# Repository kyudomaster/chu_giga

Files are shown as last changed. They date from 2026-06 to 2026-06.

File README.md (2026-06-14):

# Chu Giga Project Overview

## Project goal

This project aims to create an open-source Chunithm controller using a Raspberry Pi Pico.
The hardware and overall design is heavily inspired by [WhoWeChina's chu_pico controller](https://github.com/whowechina/chu_pico).

This project also includes software that can be used with SegaTools-Compatible game dumps.

We try to fully document the design and include instructions on how to build this controller yourself.

## Current status

We have barely even gotten started lmao:

### PCB

25%
There are first prototypes of the PCBs already, the ToF boards seem to be great, but the slider currently has the wrong pinout for LEDs so a new version needs to be made and tested.
The mainboard has not been properly tested yet and may need more power input to handle all the LEDs.

### Firmware

5%
Basic sensor drivers exist, but require some more work.
There is no firmware for LEDs or actual input handling yet.

### Software

0%
We only figured out that we need our own `chuniio.dll` today.

### CAD

10%
There is a first version of the LGP panel for the slider, but nothing has been made or tested yet.
The actual case and other components also do not exist yet.

## Features

The controller uses:

- A 32-zone capacitive PCB slider. (MPR121)
- 12 ToF Air sensors. (VL53L0X)
- 3 utility buttons. (Test, Service and Coin)
- RGB Lighting for the slider. (Slider only)

## Project Scope

This repository aims to document not only the final implementation, but also the reasoning behind the design decisions. (Or lack of reasoning when that is applicable :3)

The goal is that a future contributor should be able to understand:

- How the controller works.
- Why the specific hardware was chosen.
- How the firmware is structured.
- How communication with the game works.
- How to build your own controller.

## Supported Software

The controller is intended to support:

- Chunithm cabinet dumps through segatools.
- Umiguri.
- Maybe other games... (simple keyboard output)

Additional software may be supported in the future. (The ToF sensors technically allow for 2 Axis movement.)

## Major Components

The project consists of 4 major components:

### 1. Hardware

Documentation covering:

- PCB Designs.
- Schematics.
- Component choices.
- Assembly instructions.

### 2. Mechanical Design

Documentation covering:

- CAD Files.
- Printed/CNCd parts.
- Additional parts.
- Assembly instructions.

### 3. Firmware

Firmware running on a Raspberry Pi Pico.

Responsibilities include:

- Reading sensors.
- Processing inputs.
- Managing calibration.
- Communicating with the PC.

### 4. PC Interface Software

A custom `chuniio.dll` implementation to be used with SegaTools.

Responsibilities include:

- Receiving controller input.
- Translating controller state into SegaTools-compatible input.
- Providing an interface between the controller and the game.

## Documentation

The documentation is organized into the separate major components and build, assembly and installation guides.
You can find said documentation in the [`docs`](docs/Introduction.md)

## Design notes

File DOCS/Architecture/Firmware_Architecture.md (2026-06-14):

# Firmware Architecture

This section details how the firmware running on the Raspberry Pi Pico is structured.

## Responsibilities

The firmware is responsible for:

- Reading the sensors on the controller, both the capacitive touch and ToF sensors.
- Processing this sensor data into 'input'.
- Maintaining a controller state.
- Communicating this state with the PC.
- Taking LED information from the PC and providing this to the LEDs on the slider PCB.

The firmware is not responsible for:

- Anything game-specific.
- SegaTools integration.
- Input mapping in the game.

## Layers

The firmware consists of different layers which only talk to the layer beneath them.

We have the physical hardware which feeds into sensor boards; 12 VL53L0X ToF sensors and 3 MPR121 Capacitive touch sensors.

We have drivers which can talk to the sensors over i2c.

The input processing talks to the drivers and converts that information into actual inputs.

The controller state checks what inputs are given at any moment and the USB communication provides the state to the PC.

The communication also takes back in LED information from the PC and provides it to the LED Drivers.

## Controller state

The firmware maintains a hardware-agnostic Controller state.
Different communication layers may expose this state as a Chunithm-specific device, a generic game controller, or a keyboard without affecting the underlying sensor processing.

Chunithm itself only requires 32 Zones and 6 Air zones. But with our hardware, it's possible to measure when we are between touch zones on the PCB too... , meaning we can have up to 93 touch zones and a free moving air zone. (With both height and X-location information.)

Regardless, the state should contain information about which of the utility buttons are pressed, and which ground and air zones are touched.

The controller state is independent from any communication protocol. Multiple communication interfaces may expose the same state simultaneously, allowing compatibility with different software without changing firmware configuration.

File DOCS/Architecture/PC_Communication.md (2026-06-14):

# PC Communication

The game is hooked into by segatools which acts as if the game is actually running in a cabinet and handles all IO etc.
Segatools has its own chuniio.dll included in chunihook.dll, which takes keyboard input and maps it to the slider.

sdfghjkl mapping to four touch zones on the slider each and space to all IR leds in the air.

A custom chuniio can be made depending on a controller which will handle communication between the game and the controller. (The raspberry pi pico in this case)

This `.dll` will check what the current state of the pico is. (buttons pressed... slider touched... airstrings played)

## Outputs

There are 3 different output types currently implemented in the controller.

One with an accompanying `chuniio.dll` for the arcade dumps.
One Game controller with axes etc.
One NKRO Keyboard.

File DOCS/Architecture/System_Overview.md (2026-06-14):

# System Overview

The Chu Giga controller intends to emulate a real original Chunithm controller, with a 32-zone slider and 'Air strings'.
Instead of using interrupting IR sensors in 6 rows in the air, we are using 12 ToF sensors to emulate this behaviour instead. The main reason for this being space savings.

A completely flat controller like this is easier to store away and requires less setup when grabbing it out of storage for a quick game.

## Original hardware [ref](https://blog.pinapelz.com/blog/umiguri/)

The original Chunithm controller has a ground slider input and air input, as well as 2 utility buttons and LED lighting.

The ground slider corresponds to 16 touch zones in the game, but actually has 32 touch zones itself because some harder songs require touches while holding a note.

The 'Air strings' are 6 Infrared LEDs on one side, and 6 receivers on the other side in the air above the slider.
Interrupting the beams is how the game detects air input.

The game also reads 2 utility buttons (Test and Service) and typically has a coin slot for credits.

Furthermore, the original controller has LED lighting all over, and most importantly on the ground slider itself, Illuminating the 16 touch zones and dividers between the zones. (31 LEDs total).

We mostly include these four separate features in the Chu Giga controller.

## System Requirements

We want this controller to be to scale with the arcade version, which guides most of the slider dimensions.

Other than that we also must have:

- 32 independent slider zones.
- Some form of Air input which corresponds to 6 different zones.
- The input to be low latency enough to play the game.
- The controller to be compatible with SegaTools to play with arcade dumps.
- The controller should also be compatible with other games... so emulating a keyboard or a controller is appropriate.

## Physical Architecture

To keep costs down and assembly reasonable and more fool-proof, since I had very little experience with electronic design before this, the controller is split up into separate components.

- There is one PCB for the ground slider.
- There are two separate PCBs for the air strings.
- There is one 'mainboard' that the other PCBs connect to, and which in turn connects to the PC.
- All PCBs are kept in place with an enclosure which can be 3D-printed or partially CNC milled.
- There are several other parts like a light guide plate, diffusion film etc. inspired by the chu_pico by [WhoWeChina](https://github.com/whowechina/chu_pico)

## Electronic Architecture

The controller uses capacitive touch sensors for the ground slider. This is an easy and cheap way to get touch input like we want it, and it allows for the PCB to be quite simple.

The air strings use time of flight sensors rather than IR beam interruption. The main reason for this being that this allows for slightly more flexible input, and that the air strings can be in plane with the ground slider, meaning the entire controller can be flat and compact.

The controller uses a Raspberry Pi Pico for processing and communication (RP2040) and the ground slider has 33 RGB LEDs, one for all 16 horizontal zones, and 17 for the dividers. (With 2 extra on both ends.)

Furthermore, there are 3 buttons to emulate the Test, Service, and Coin functions of the original controller.

## Software Architecture

For the controller to communicate with the game, we must emulate a 'real controller'.

Thankfuly we do not need to do the work for this, but we can 'simply' use SegaTools.
SegaTools can either use keyboard input or a custom `.dll` for the controller.

Since I'm in this deep already, I decided to go for a custom `chuniio.dll` which is the bridge between the game and the controller.

The controller handles the USB Communication and some sensor processing.

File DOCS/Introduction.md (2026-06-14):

# Chu Giga Documentation

Welcome to the Chu Giga documentation.

This documentation covers the hardware, firmware, software, and assembly process of the project.

## Architecture

Documentation describing how the system is designed.

- [System Overview](Architecture/System_Overview.md)
- [Firmware Architecture](Architecture/Firmware_Architecture.md)
- [PC Communication](Architecture/PC_Communication.md)
- [Controller State](Architecture/Controller_State.md)

## Hardware

Documentation describing the electronics and the 3D prints etc.

### PCB

- [PCB Overview](Hardware/PCB_Overview.md)
- [Mainboard](Hardware/Mainboard.md)
- [Slider PCB](Hardware/Slider_PCB.md)
- [Air Strings](Hardware/Air_PCB.md)

### CAD

- [Casing](Hardware/Casing.md)
- [Light-Guide Panel](Hardware/LGP.md)

## Firmware

Documentation describing the RP2040 based firmware.

- [Sensor Drivers](Firmware/Sensor_Drivers.md)
- [Input Processing](Firmware/Input_Processing.md)
- [LED Drivers](Firmware/LED_Drivers.md)
- [HID Implementation](Firmware/HID_Implementation.md)
- [Testing](Firmware/Testing.md)

## Software

Documentation describing the PC-side software.

- [`chuniio.dll`](Software/chuniio_DLL.md)
- [Configuration tool](Software/Configuration_Tool.md)

## Build Guide

Documentation describing how to build the controller.

- [Bill of Materials](Build_Guide/BOM.md)
- [PCB Assembly](Build_Guide/PCB_Assembly.md)
- [General Assembly](Build_Guide/Controller_Assembly.md)
- [Flashing Firmware](Build_Guide/Flashing_Firmware.md)
- [First-Time Setup](Build_Guide/First_Time_Setup.md)

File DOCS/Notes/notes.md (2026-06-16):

# Working Notes

The firmware consists of USB reporting, which reports a controller state.

The controller state which is decided by using the sensor drivers and the sensor drivers which get values from the sensors.

## Nuan notities

[Linkje](https://xanthium64.rssing.com/chan-53317880/article65.html)

## Wat gaan we doen

Ik kan twee dingetjes maken, 1 die de 3 MPR uitleest en 1 die de 12 VL53L0X uitleest

Ik kan nog een ding maken die de output daarvan omzet naar een controller status die daarna weer door de USB bullshit gezien wordt.

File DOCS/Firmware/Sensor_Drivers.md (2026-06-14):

# Sensor drivers

The controller has two types of sensors and it has some buttons.

- VL53L0X ToF sensors.
- MPR121 Capacitive touch sensors.
- Buttons.

## ToF sensors

Time of Flight sensors work based on ...

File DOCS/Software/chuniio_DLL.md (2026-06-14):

# `chuniio.dll`

This is `chuniio.h`:

```c
#pragma once

/*
   CHUNITHM CUSTOM IO API

   Changelog:

   - 0x0100: Initial API version (assumed if chuni_io_get_api_version is not
     exported)
   - 0x0101: Fix IR beam mappings
   - 0x0102: Add air tower led and billboard support
*/

#include <windows.h>

#include <stdbool.h>
#include <stdint.h>

enum {
    CHUNI_IO_OPBTN_TEST = 0x01,
    CHUNI_IO_OPBTN_SERVICE = 0x02,
    CHUNI_IO_OPBTN_COIN = 0x04,
};
```

```c
/* Get the version of the Chunithm IO API that this DLL supports. This
   function should return a positive 16-bit integer, where the high byte is
   the major version and the low byte is the minor version (as defined by the
   Semantic Versioning standard).

   The latest API version as of this writing is 0x0101. */

uint16_t chuni_io_get_api_version(void);
```

```c
/* Initialize JVS-based input. This function will be called before any other
   chuni_io_jvs_*() function calls. Errors returned from this function will
   manifest as a disconnected JVS bus.

   All subsequent calls may originate from arbitrary threads and some may
   overlap with each other. Ensuring synchronization inside your IO DLL is
   your responsibility.

   Minimum API version: 0x0100 */

HRESULT chuni_io_jvs_init(void);
```

```c
/* Poll JVS input.

   opbtn returns the cabinet test/service state, where bit 0 is Test and Bit 1
   is Service.

   beam returns the IR beams that are currently broken, where bit 0 is the
   lowest IR beam and bit 5 is the highest IR beam, for a total of six beams.

   Both bit masks are active-high.

   Note that you cannot instantly break the entire IR grid in a single frame to
   simulate hand movement; this will be judged as a miss. You need to simulate
   a gradual raising and lowering of the hands. Consult the proof-of-concept
   implementation for details.

   NOTE: Previous releases of Segatools mapped the IR beam inputs incorrectly.
   Please ensure that you advertise an API version of at least 0x0101 so that
   the correct mapping can be used.

   Minimum API version: 0x0100
   Latest API version: 0x0101 */

void chuni_io_jvs_poll(uint8_t *opbtn, uint8_t *beams);
```

```c
/* Read the current state of the coin counter. This value should be incremented
   for every coin detected by the coin acceptor mechanism. This count does not
   need to persist beyond the lifetime of the process.

   Minimum API version: 0x0100 */

void chuni_io_jvs_read_coin_counter(uint16_t *total);
```

```c
/* Initialize touch slider emulation. This function will be called before any
   other chuni_io_slider_*() function calls.

   All subsequent calls may originate from arbitrary threads and some may
   overlap with each other. Ensuring synchronization inside your IO DLL is
   your responsibility.

   Minimum API version: 0x0100 */

HRESULT chuni_io_slider_init(void);
```

This is how a chunithm touch slider layout works.

```c
/* Chunithm touch slider layout:

                               ^^^ Toward screen ^^^

----+----+----+----+----+----+----+----+----+----+----+----+----+----+----+----+
 31 | 29 | 27 | 25 | 23 | 21 | 19 | 17 | 15 | 13 | 11 |  9 |  7 |  5 |  3 |  1 |
----+----+----+----+----+----+----+----+----+----+----+----+----+----+----+----+
 32 | 30 | 28 | 26 | 24 | 22 | 20 | 18 | 16 | 14 | 12 | 10 |  8 |  6 |  4 |  2 |
----+----+----+----+----+----+----+----+----+----+----+----+----+----+----+----+

   There are a total of 32 regions on the touch slider. Each region can return
   an 8-bit pressure value. The operator menu allows the operator to adjust the
   pressure level at which a region is considered to be pressed; the factory
   default value for this setting is 20. */
```

```c
/* Callback function supplied to your IO DLL. This must be called with a
   pointer to a 32-byte array of pressure values, one byte per slider cell.
   See above for layout and pressure threshold information.

   The callback will copy the pressure state data out of your buffer before
   returning. The pointer will not be retained. */

typedef void (*chuni_io_slider_callback_t)(const uint8_t *state);
```

```c
/* Start polling the slider. Your DLL must start a polling thread and call the
   supplied function periodically from that thread with new input state. The
   update interval is up to you, but if your input device doesn't have any
   preferred interval then 1 kHz is a reasonable maximum frequency.

   Note that you do have to have to call the callback "occasionally" even if
   nothing is changing, otherwise the game will raise a comm timeout error.

   Minimum API version: 0x0100 */

void chuni_io_slider_start(chuni_io_slider_callback_t callback);
```

```c
/* Stop polling the slider. You must cease to invoke the input callback before
   returning from this function.

   This *will* be called in the course of regular operation. For example,
   every time you go into the operator menu the slider and all of the other I/O
   on the cabinet gets restarted.

   Following on from the above, the slider polling loop *will* be restarted
   after being stopped in the course of regular operation. Do not permanently
   tear down your input driver in response to this function call.

   Minimum API version: 0x0100 */

void chuni_io_slider_stop(void);
```

```c
/* Update the RGB lighting on the slider. A pointer to an array of 32 * 3 = 96
  bytes is supplied, organized in BRG format.
   The first set of bytes is the right-most slider key, and from there the bytes
   alternate between the dividers and the keys until the left-most key. 
   There are 31 illuminated sections in total.

   Minimum API version: 0x0100 */

void chuni_io_slider_set_leds(const uint8_t *rgb);
```

```c
/* Initialize LED emulation. This function will be called before any
   other chuni_io_led_*() function calls.

   All subsequent calls may originate from arbitrary threads and some may
   overlap with each other. Ensuring synchronization inside your IO DLL is
   your responsibility. 

   Minimum API version: 0x0102 */

HRESULT chuni_io_led_init(void);
```

```c
/* Update the RGB LEDs. rgb is a pointer to an array of up to 63 * 3 = 189 bytes.

   Chunithm uses two chains/boards with WS2811 protocol (each logical led corresponds to 3 physical leds). 
   board 0 is on the left side and board 1 on the right side of the cab

   Board 0 has 53 LEDs:
     [0]-[49]: snakes through left half of billboard (first column starts at top)
     [50]-[52]: left side partition LEDs
   
   Board 1 has 63 LEDs:
     [0]-[59]: right half of billboard (first column starts at bottom)
     [60]-[62]: right side partition LEDs
   
   Board 2 is the slider and has 31 LEDs:
     [0]-[31]: slider LEDs right to left BRG, alternating between keys and dividers 

   Each rgb value is comprised of 3 bytes in R,G,B order

   NOTE: billboard strips have alternating direction (bottom to top, top to bottom, ...)

   Minimum API version: 0x0102 */

void chuni_io_led_set_colors(uint8_t board, uint8_t *rgb);
```

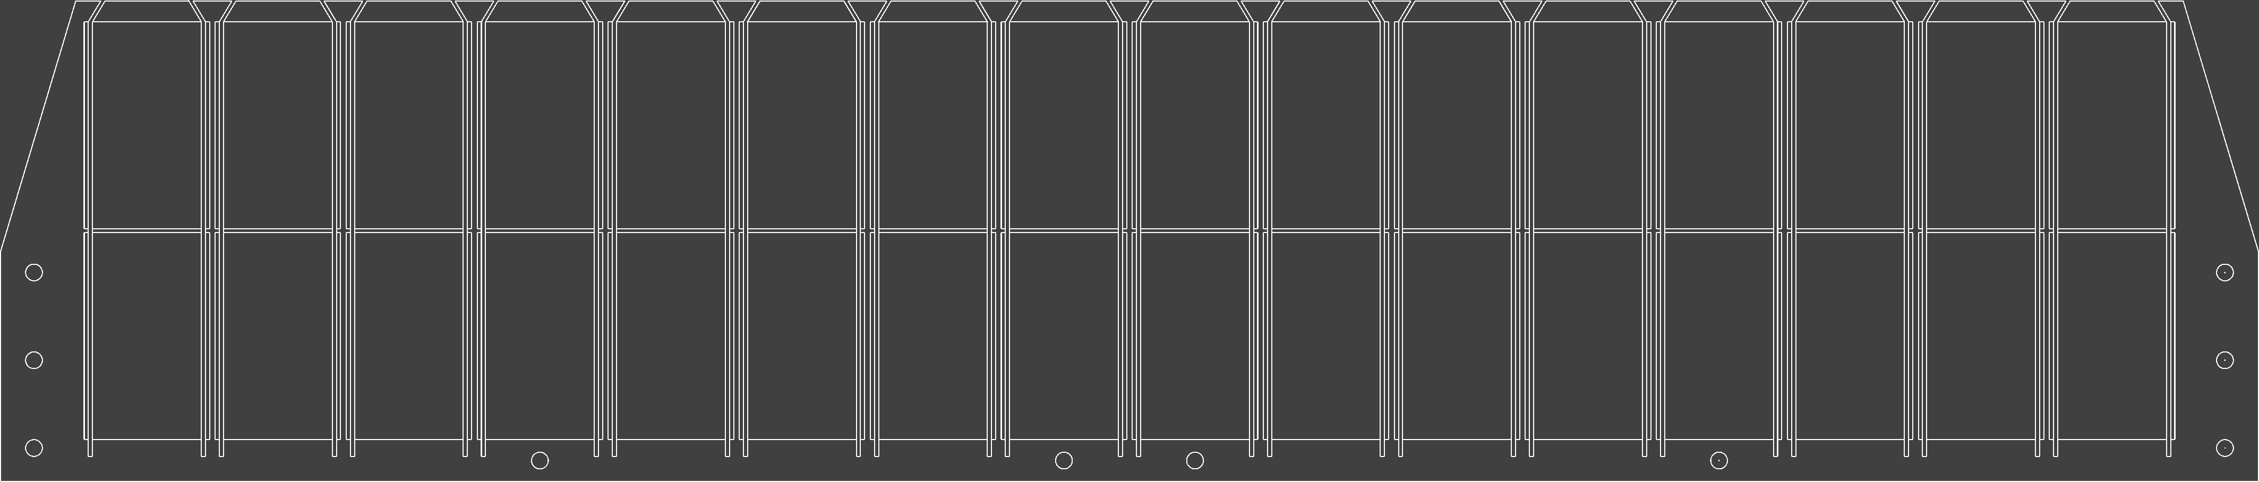
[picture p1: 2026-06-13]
PCB/chu_giga/Extra Symbols/LGP.png

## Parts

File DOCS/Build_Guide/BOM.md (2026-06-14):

# Bill of Materials

## PCBs

## Electronic Components

## 3D Prints / CNC stuff

## Other hardware

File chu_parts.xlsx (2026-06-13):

Chu_Giga | BOM | Link to Part
Name | Number
Raspberry Pi Pico (2)(W) | 1 | https://nl.mouser.com/ProductDetail/Raspberry-Pi/SC0915?qs=T%252BzbugeAwjgnLi4azxXVFA%3D%3D
USB-C socket ((918-418K2023S40001 or KH-TYPE-C-16P) | 1 | https://nl.mouser.com/ProductDetail/Same-Sky/UJ20-C-H-G-SMT-1-P16-TR?qs=IKkN%2F947nfA6nby92vSKkw%3D%3D
WS2812B-4020 side-facing RGB LEDs. | 36 | https://nl.mouser.com/ProductDetail/Inolux/IN-PI42TASPRPGPB?qs=mAH9sUMRCttLpM33XCs9Lg%3D%3D
TCA9548APWR (TSSOP-24) I2C multiplexer | 1 | https://nl.mouser.com/ProductDetail/Texas-Instruments/TCA9548APWR
MPR121 modules | 3 | https://www.reichelt.com/ie/en/shop/product/developer_boards_-_board_for_capacitive_touch_sensors_mpr121-291455
ST VL53L0X ToF Sensors GY530 | 8 | https://nl.aliexpress.com/item/1005006193300678.html?scm_id=1007.40050.354490.0&scm-url=1007.40050.354490.0
0603 5.1k Ohm resistors | 12 | https://nl.mouser.com/ProductDetail/SEI-Stackpole/RMCF0603FT5K10?qs=FESYatJ8odLDGF0bJ%2FNNFQ%3D%3D
0603 1 microF capacitors | 8 | https://nl.mouser.com/ProductDetail/Murata-Electronics/GXT188R71C105KE13D?qs=d0WKAl%252BL4KYvDVwMHfkoxw%3D%3D
EVQP46B3M tiny tactile switches | 3 | https://nl.mouser.com/ProductDetail/Panasonic/EVQ-P46B3M?qs=0aNVN3t2tDvy2i5lONF68A%3D%3D
PCB Parts |  | For 1 Controller
Name | Part # | Amount | Price per item | Link to Part | Legend
Raspberry Pi Pico (2)(W) | SC0915 | 1 | €3.44 | https://nl.mouser.com/ProductDetail/Raspberry-Pi/SC0915?qs=T%252BzbugeAwjgnLi4azxXVFA%3D%3D | Touchpads
USB-C same sky | UJ20-C-H-G-SMT-1-P16-TR | 1 | €0.46 | https://nl.mouser.com/ProductDetail/Same-Sky/UJ20-C-H-G-SMT-1-P16-TR?qs=IKkN%2F947nfA6nby92vSKkw%3D%3D | Controller
0805 1 microF Capacitors | CL21B105KAFNNNG | 2 | €0.86 | https://nl.mouser.com/ProductDetail/Samsung-Electro-Mechanics/CL21B105KAFNNNG | Time-Of-Flight sensor
TE connectivity 6 pin header | 640455-6 | 1 | €0.19 | https://nl.mouser.com/ProductDetail/TE-Connectivity/640455-6?qs=%2F35zJ5USjokIauqXdzyPIA%3D%3D
TE Connectivity 6 pin housing | 1375820-6 | 1 | €0.22 | https://nl.mouser.com/ProductDetail/TE-Connectivity-AMP/1375820-6?qs=A%252B%2FNCR0PvNXoGB8b1%252BcKvQ%3D%3D
TE connectivity 4 pin header | 640455-4 | 2 | €0.10 | https://nl.mouser.com/ProductDetail/TE-Connectivity/640455-4?qs=%2F35zJ5USjolIN5b4JrZGlg%3D%3D
TE Connectivity Contact | 1445336-1 | 14 | €0.09 | https://nl.mouser.com/ProductDetail/TE-Connectivity-AMP/1445336-1?qs=KdTYp8tcPgmCxccbDVTrIw%3D%3D
TE Connectivity 4 pin housing | 1375820-4 | 2 | €0.19 | https://nl.mouser.com/ProductDetail/TE-Connectivity-AMP/1375820-4?qs=HSGlLeu24BO3HoziPibDTg%3D%3D
Panasonic tiny tactile switches | EVQ-P46B3M | 3 | €0.68 | https://nl.mouser.com/ProductDetail/Panasonic/EVQ-P46B3M?qs=0aNVN3t2tDvy2i5lONF68A%3D%3D
5.1K Ohm 0805 Thick Film Resistor | CRCW08055K10JNEA | 2 | €0.09 | https://nl.mouser.com/ProductDetail/Vishay/CRCW08055K10JNEA?qs=8UjxRNpjuUKaOnmI6WLdBA%3D%3D
M3 Screws |  | 4 |  |  | Cost per PCB | €10.09
MPR121 Module (Capacitive touch) | N/A | 3 | €1 | https://nl.aliexpress.com/item/1005009068217313.html
0805 1 microF Capacitors | CL21B105KAFNNNG | 8 | €0.86 | https://nl.mouser.com/ProductDetail/Samsung-Electro-Mechanics/CL21B105KAFNNNG
Inolux 4020 Side View RGB LED 4-Pin with Integrated IC | IN-PI42TASPRPGPB | 33 | €0.65 | https://nl.mouser.com/ProductDetail/Inolux/IN-PI42TASPRPGPB?qs=mAH9sUMRCttLpM33XCs9Lg%3D%3D
TE connectivity 6 pin header | 640455-6 | 1 | €0.19 | https://nl.mouser.com/ProductDetail/TE-Connectivity/640455-6?qs=%2F35zJ5USjokIauqXdzyPIA%3D%3D
TE Connectivity 6 pin housing | 1375820-6 | 1 | €0.22 | https://nl.mouser.com/ProductDetail/TE-Connectivity-AMP/1375820-6?qs=A%252B%2FNCR0PvNXoGB8b1%252BcKvQ%3D%3D
TE Connectivity Contact | 1445336-1 | 6 | €0.09 | https://nl.mouser.com/ProductDetail/TE-Connectivity-AMP/1445336-1?qs=KdTYp8tcPgmCxccbDVTrIw%3D%3D
M3 Screws |  | 5 |  |  | Cost per PCB | €32.28
0805 330 Ohm Resistor
TCA9548APWR (TSSOP-24) I2C multiplexer | TCA9548APWR | 1 | €1.14 | https://nl.mouser.com/ProductDetail/Texas-Instruments/TCA9548APWR
0805 1 microF Capacitors | CL21B105KAFNNNG | 1 | €0.86 | https://nl.mouser.com/ProductDetail/Samsung-Electro-Mechanics/CL21B105KAFNNNG
TE Connectivity 4 pin housing | 1375820-4 | 1 | €0.19 | https://nl.mouser.com/ProductDetail/TE-Connectivity-AMP/1375820-4?qs=HSGlLeu24BO3HoziPibDTg%3D%3D
TE connectivity 4 pin header | 640455-4 | 1 | €0.10 | https://nl.mouser.com/ProductDetail/TE-Connectivity/640455-4?qs=%2F35zJ5USjolIN5b4JrZGlg%3D%3D
Time-of-Flight Sensor board | ST VL53L0X - GY530 (Sensor/Board) | 6 | €1.00 | https://nl.aliexpress.com/item/1005009427024502.html
TE Connectivity Contact | 1445336-1 | 4 | €0.09 | https://nl.mouser.com/ProductDetail/TE-Connectivity-AMP/1445336-1?qs=KdTYp8tcPgmCxccbDVTrIw%3D%3D
M3 Screws |  | 2
5.1K Ohm 0805 Thick Film Resistor | CRCW08055K10JNEA | 1 | €0.09 | https://nl.mouser.com/ProductDetail/Vishay/CRCW08055K10JNEA?qs=8UjxRNpjuUKaOnmI6WLdBA%3D%3D | Cost per PCB | €8.74
 |  |  |  |  | Total per Controller | €59.85
Laser cut parts
CNC parts
Other

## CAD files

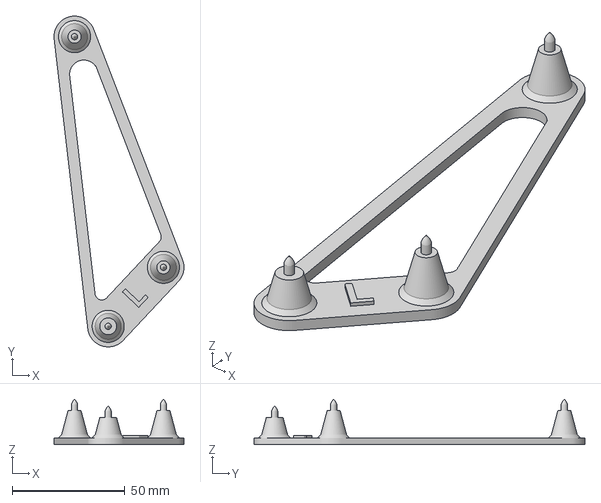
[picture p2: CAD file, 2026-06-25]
CAD/Left-Holder-Chu-Giga.3mf
57.8 x 147.0 x 20.0 mm

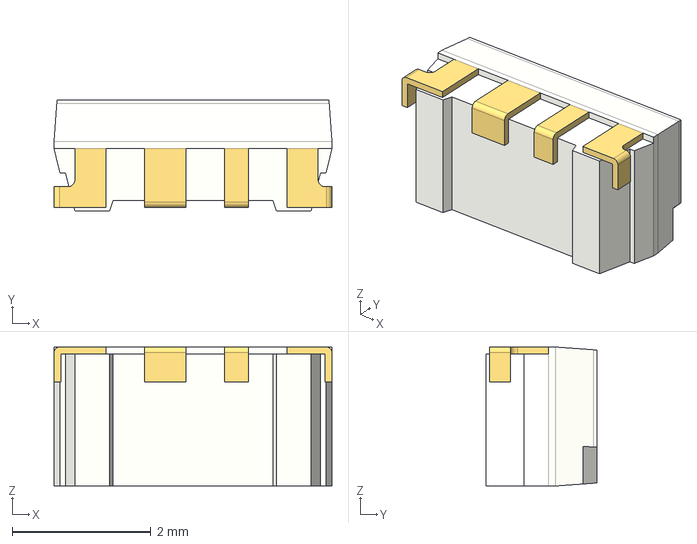
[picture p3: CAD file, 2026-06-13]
PCB/chu_controller/Extra Symbols/LED.stp
4.00 x 1.60 x 2.00 mm

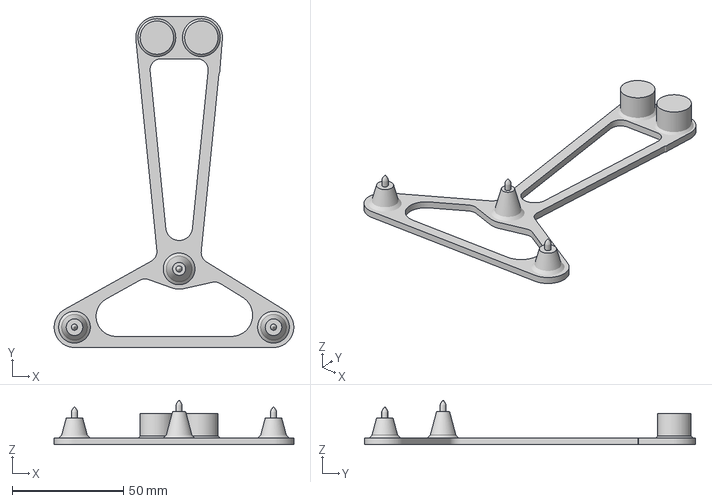
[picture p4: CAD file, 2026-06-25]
CAD/Center-Holder-Chu-Giga.3mf
107.8 x 148.8 x 20.0 mm

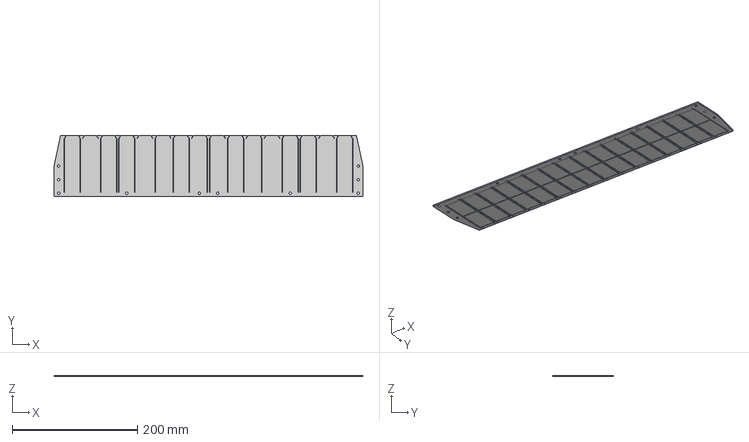
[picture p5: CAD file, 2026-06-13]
PCB/chu_controller/Extra Symbols/LGP.step
493.5 x 97.0 x 2.00 mm

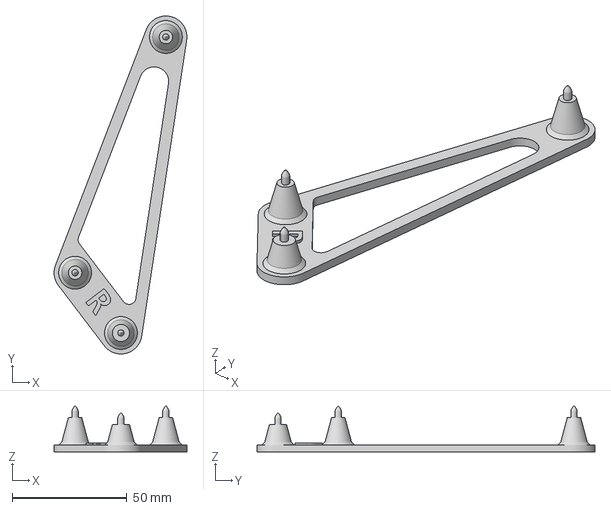
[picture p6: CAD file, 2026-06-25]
CAD/Right-Holder-Chu-Giga.3mf
57.8 x 147.0 x 20.0 mm

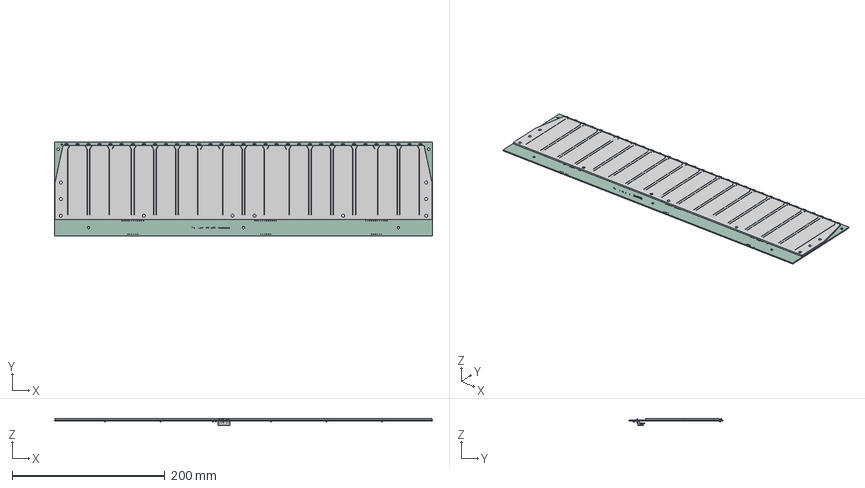
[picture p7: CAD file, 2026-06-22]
CAD/chu-touch.step
495.0 x 123.0 x 9.44 mm
IN-PI42TASPRPGPB x 33
Light Guide Panel V2
R_0805_2012Metric
C_0805_2012Metric x 8
chu_touchpads_silkscreen x 2
chu_touchpads_PCB

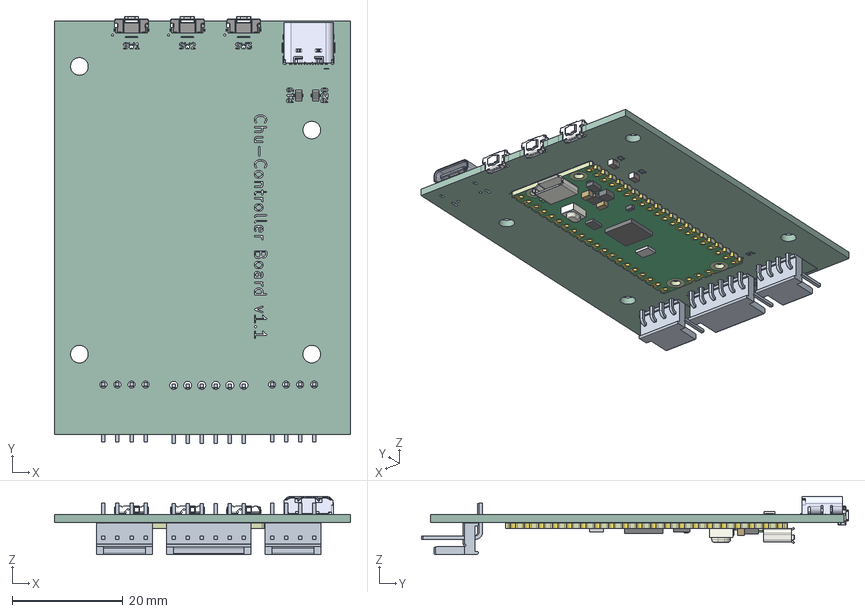
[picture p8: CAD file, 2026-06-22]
CAD/chu-controller.step
53.5 x 77.2 x 10.6 mm
EVQ-P46B3M x 3
UJ20-C-H-G-SMT-1-P16-TR
R_0805_2012Metric x 2
RaspberryPi_Pico_Module_KiCad
C_0805_2012Metric x 2
chu_controller_silkscreen x 2
chu_controller_PCB

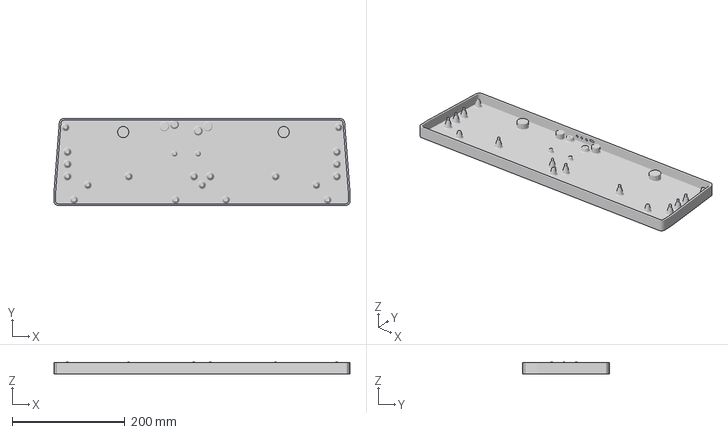
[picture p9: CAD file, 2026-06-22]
CAD/Chuni bottom case.3mf
526.0 x 154.5 x 21.0 mm

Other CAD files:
PCB/chu_touchpads/Extra Symbols/LED(Rotated).step
PCB/chu_giga/Extra Symbols/LED(Rotated).step
PCB/chu_tof/Extra Symbols/LED(Rotated).step
PCB/chu_controller/Extra Symbols/LED(Rotated).step
CAD/chu-tof.step
PCB/chu_controller/Extra Symbols/LGP.dxf
PCB/chu_giga/Extra Symbols/LGP.dxf
PCB/chu_tof/Extra Symbols/LGP.dxf
PCB/chu_touchpads/Extra Symbols/LGP.dxf

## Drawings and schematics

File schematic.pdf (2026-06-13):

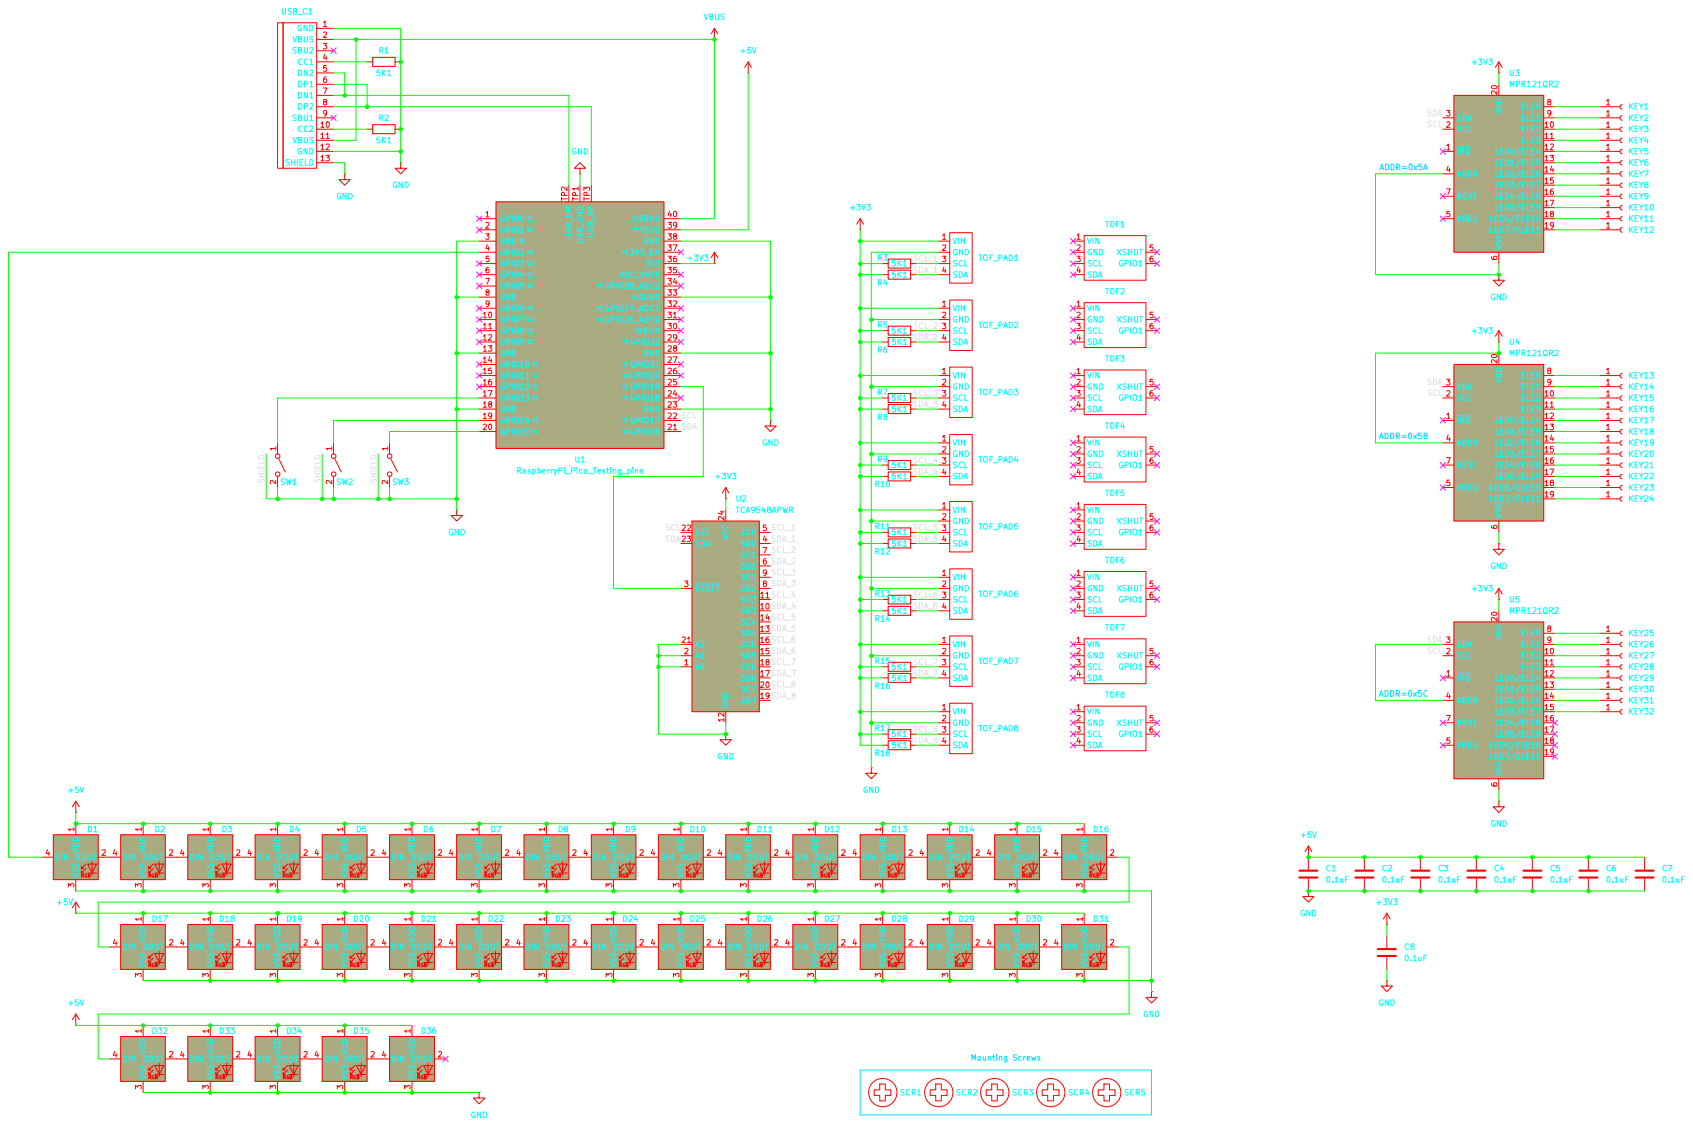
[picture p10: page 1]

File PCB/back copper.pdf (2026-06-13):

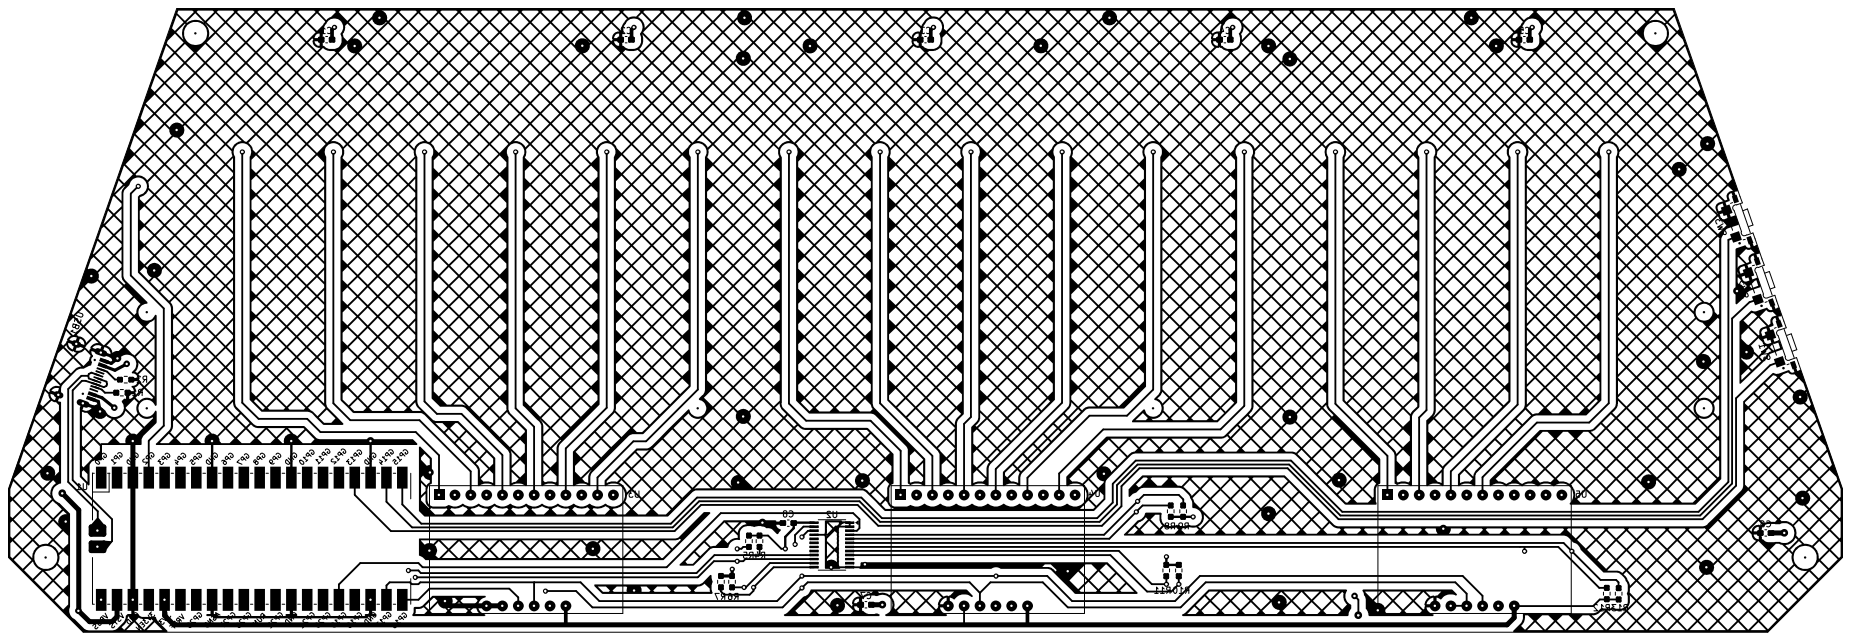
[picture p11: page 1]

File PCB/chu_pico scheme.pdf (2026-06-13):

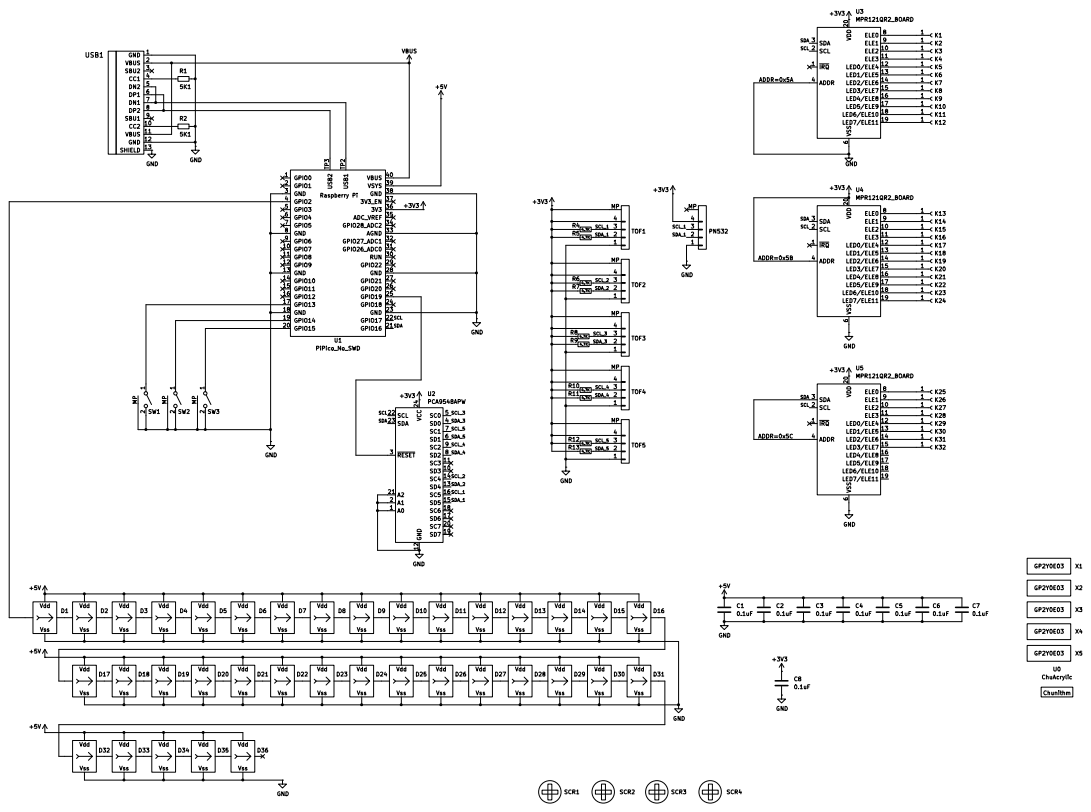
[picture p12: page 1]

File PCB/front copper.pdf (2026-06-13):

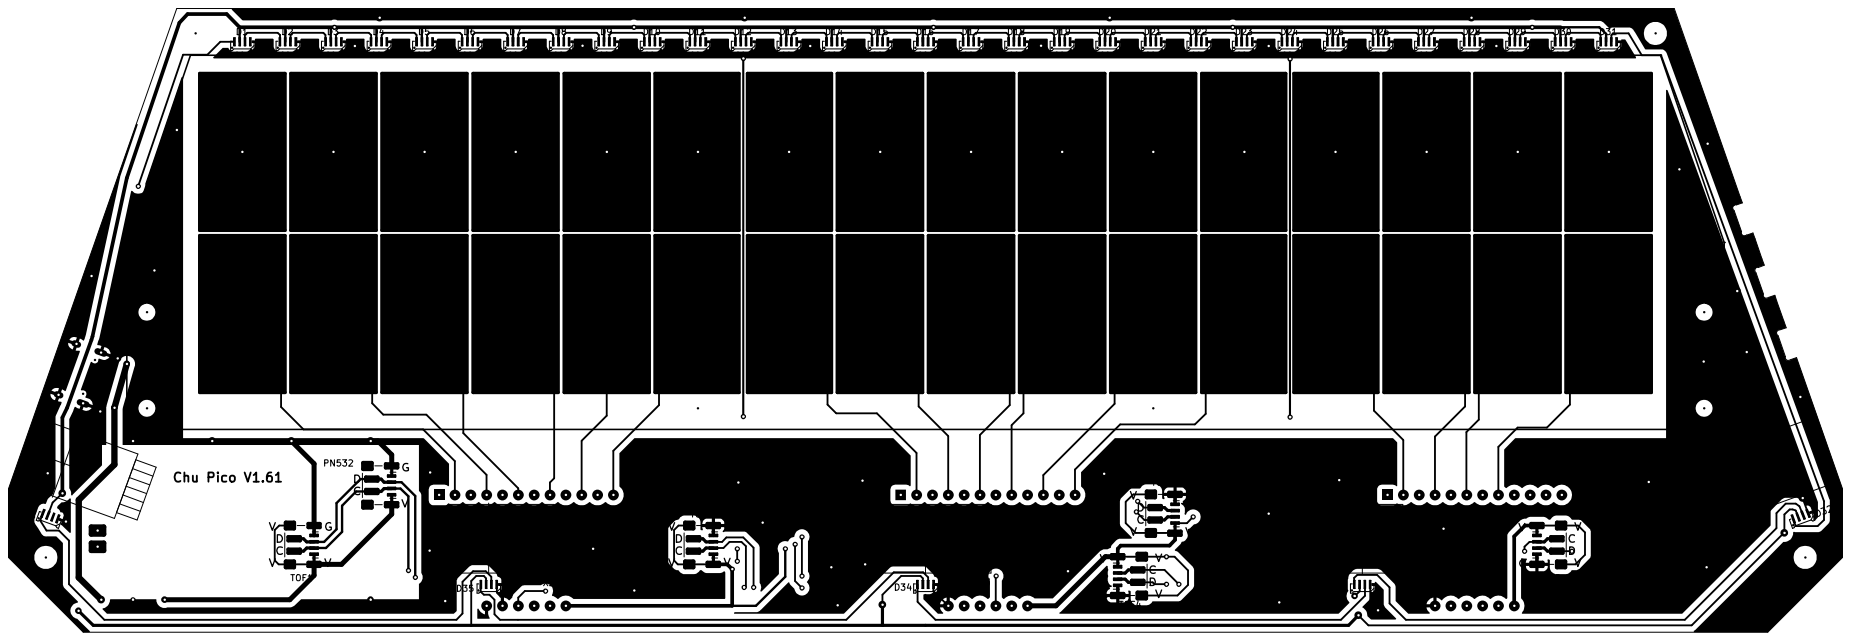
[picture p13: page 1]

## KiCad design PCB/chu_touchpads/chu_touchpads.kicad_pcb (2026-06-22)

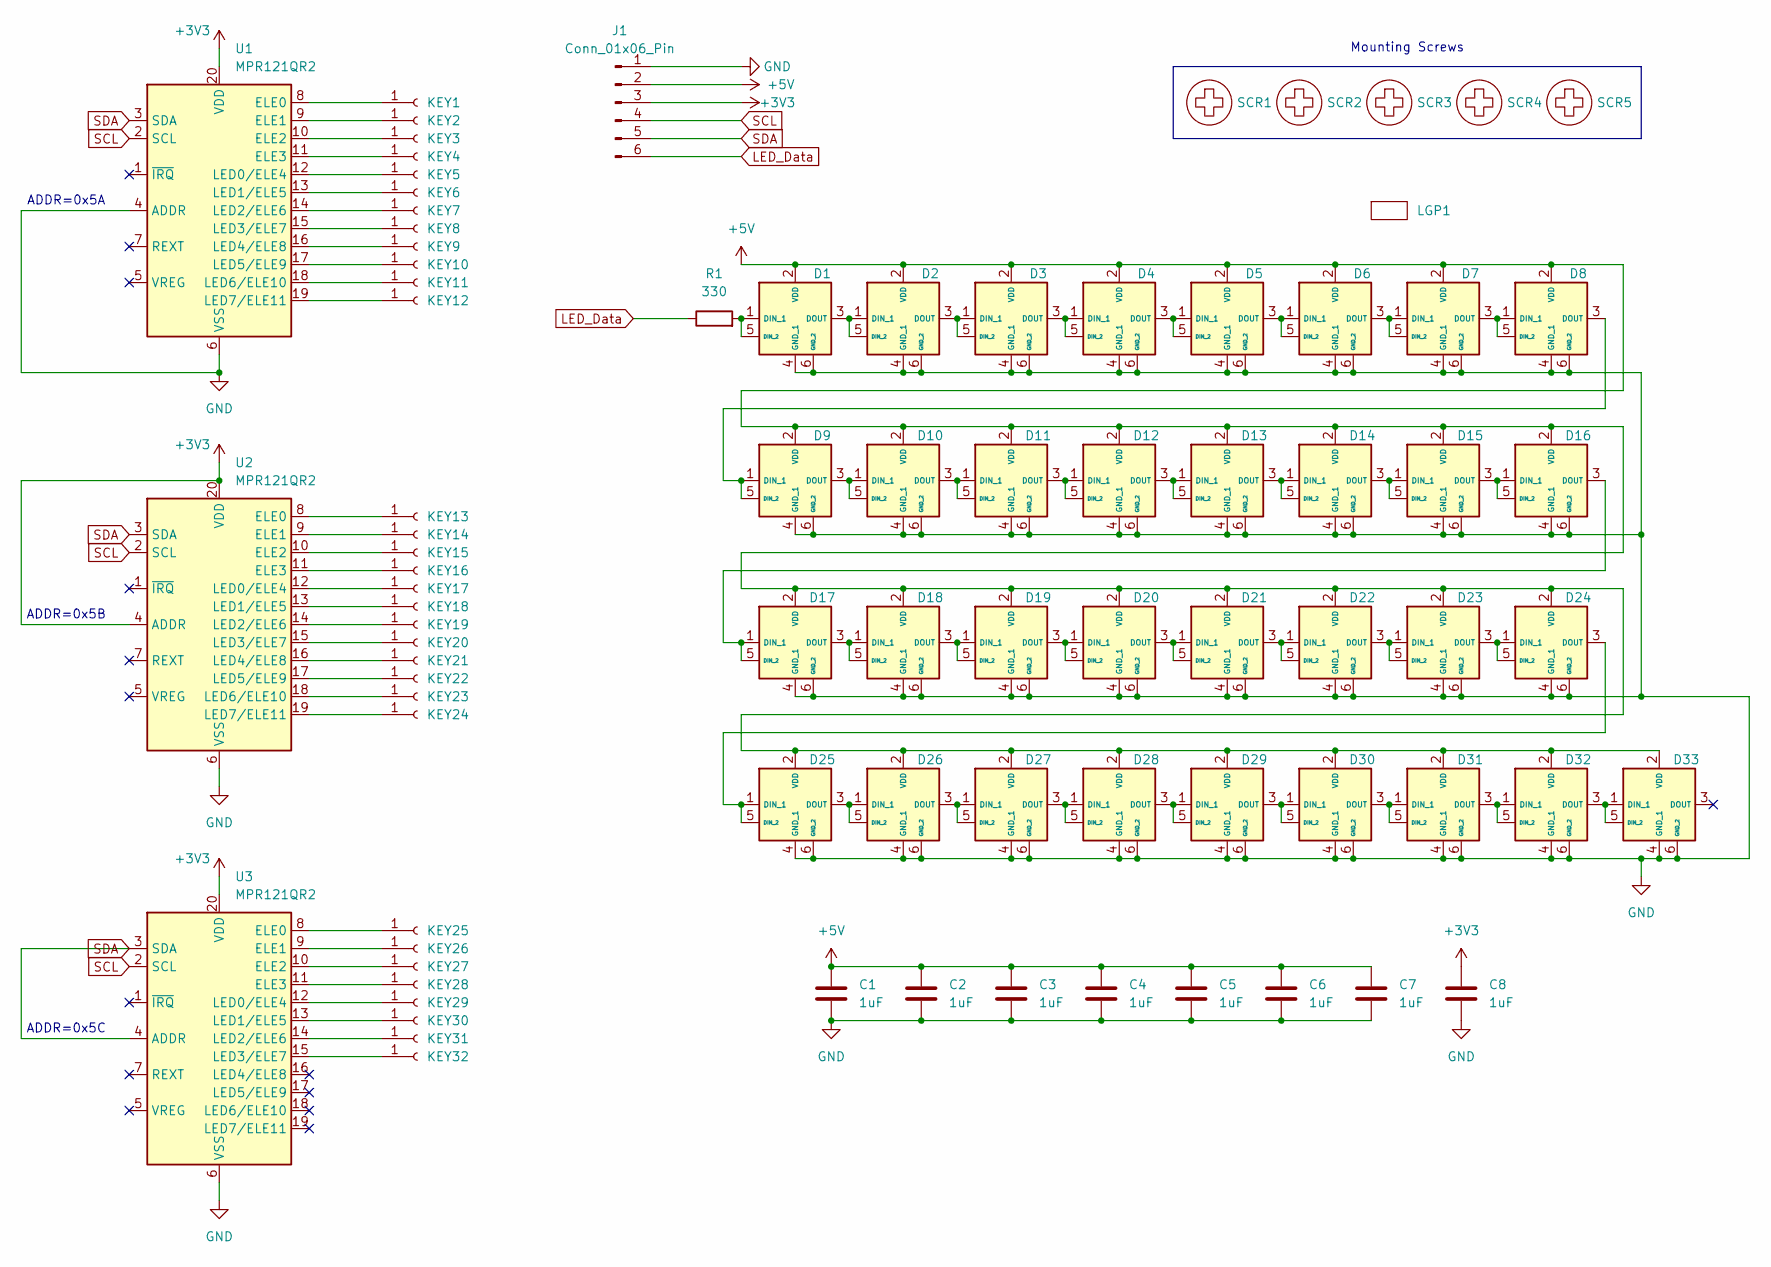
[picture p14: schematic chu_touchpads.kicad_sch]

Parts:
C1, C2, C3, C4, C5, C6, C7, C8: 1uF; C_0805_2012Metric_Pad1.18x1.45mm_HandSolder
D1, D2, D3, D4, D5, D6, D7, D8, D9, D10, D11, D12, D13, D14, D15, D16, D17, D18, D19, D20, D21, D22, D23, D24, D25, D26, D27, D28, D29, D30, D31, D32, D33: WS2812B; INPI42TASPRPGPB; Mouser Part Number 743-IN-PI42TASPRPGPB
J1: Conn_01x06_Pin; SHDRRA6W88P0X254_1X6_1524X254X610P
KEY1, KEY2, KEY3, KEY4, KEY5, KEY6, KEY7, KEY8, KEY9, KEY10, KEY11, KEY12, KEY13, KEY14, KEY15, KEY16, KEY17, KEY18, KEY19, KEY20, KEY21, KEY22, KEY23, KEY24, KEY25, KEY26, KEY27, KEY28, KEY29, KEY30, KEY31, KEY32: Conn_01x01_Socket; Capacitive_Touchpad_405x285
LGP1: LGP_new
R1: 330; R_0805_2012Metric_Pad1.20x1.40mm_HandSolder
SCR1, SCR2, SCR3, SCR4, SCR5: MountingHole_3.2mm_M3
U1, U2, U3: MPR121QR2; MPR121_BOARD

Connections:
+3V3: C8.1, J1.3, U1.20 (VDD), U2.4 (ADDR), U2.20 (VDD), U3.20 (VDD)
+5V: C1.1, C2.1, C3.1, C4.1, C5.1, C6.1, C7.1, D1.2 (VDD), D2.2 (VDD), D3.2 (VDD), D4.2 (VDD), D5.2 (VDD), D6.2 (VDD), D7.2 (VDD), D8.2 (VDD), D9.2 (VDD), D10.2 (VDD), D11.2 (VDD), D12.2 (VDD), D13.2 (VDD), D14.2 (VDD), D15.2 (VDD), D16.2 (VDD), D17.2 (VDD), D18.2 (VDD), D19.2 (VDD), D20.2 (VDD), D21.2 (VDD), D22.2 (VDD), D23.2 (VDD), D24.2 (VDD), D25.2 (VDD), D26.2 (VDD), D27.2 (VDD), D28.2 (VDD), D29.2 (VDD), D30.2 (VDD), D31.2 (VDD), D32.2 (VDD), D33.2 (VDD), J1.2
GND: C1.2, C2.2, C3.2, C4.2, C5.2, C6.2, C7.2, C8.2, D1.4 (GND_1), D1.6 (GND_2), D2.4 (GND_1), D2.6 (GND_2), D3.4 (GND_1), D3.6 (GND_2), D4.4 (GND_1), D4.6 (GND_2), D5.4 (GND_1), D5.6 (GND_2), D6.4 (GND_1), D6.6 (GND_2), D7.4 (GND_1), D7.6 (GND_2), D8.4 (GND_1), D8.6 (GND_2), D9.4 (GND_1), D9.6 (GND_2), D10.4 (GND_1), D10.6 (GND_2), D11.4 (GND_1), D11.6 (GND_2), D12.4 (GND_1), D12.6 (GND_2), D13.4 (GND_1), D13.6 (GND_2), D14.4 (GND_1), D14.6 (GND_2), D15.4 (GND_1), D15.6 (GND_2), D16.4 (GND_1), D16.6 (GND_2), D17.4 (GND_1), D17.6 (GND_2), D18.4 (GND_1), D18.6 (GND_2), D19.4 (GND_1), D19.6 (GND_2), D20.4 (GND_1), D20.6 (GND_2), D21.4 (GND_1), D21.6 (GND_2), D22.4 (GND_1), D22.6 (GND_2), D23.4 (GND_1), D23.6 (GND_2), D24.4 (GND_1), D24.6 (GND_2), D25.4 (GND_1), D25.6 (GND_2), D26.4 (GND_1), D26.6 (GND_2), D27.4 (GND_1), D27.6 (GND_2), D28.4 (GND_1), D28.6 (GND_2), D29.4 (GND_1), D29.6 (GND_2), D30.4 (GND_1), D30.6 (GND_2), D31.4 (GND_1), D31.6 (GND_2), D32.4 (GND_1), D32.6 (GND_2), D33.4 (GND_1), D33.6 (GND_2), J1.1, U1.4 (ADDR), U1.6 (VSS), U2.6 (VSS), U3.6 (VSS)
LED_Data: J1.6, R1.1
unnamed: D1.1 (DIN_1), D1.5 (DIN_2), R1.2
unnamed: D1.3 (DOUT), D2.1 (DIN_1), D2.5 (DIN_2)
unnamed: D2.3 (DOUT), D3.1 (DIN_1), D3.5 (DIN_2)
unnamed: D3.3 (DOUT), D4.1 (DIN_1), D4.5 (DIN_2)
unnamed: D4.3 (DOUT), D5.1 (DIN_1), D5.5 (DIN_2)
unnamed: D5.3 (DOUT), D6.1 (DIN_1), D6.5 (DIN_2)
unnamed: D6.3 (DOUT), D7.1 (DIN_1), D7.5 (DIN_2)
unnamed: D7.3 (DOUT), D8.1 (DIN_1), D8.5 (DIN_2)
unnamed: D8.3 (DOUT), D9.1 (DIN_1), D9.5 (DIN_2)
unnamed: D9.3 (DOUT), D10.1 (DIN_1), D10.5 (DIN_2)
unnamed: D10.3 (DOUT), D11.1 (DIN_1), D11.5 (DIN_2)
unnamed: D11.3 (DOUT), D12.1 (DIN_1), D12.5 (DIN_2)
unnamed: D12.3 (DOUT), D13.1 (DIN_1), D13.5 (DIN_2)
unnamed: D13.3 (DOUT), D14.1 (DIN_1), D14.5 (DIN_2)
unnamed: D14.3 (DOUT), D15.1 (DIN_1), D15.5 (DIN_2)
unnamed: D15.3 (DOUT), D16.1 (DIN_1), D16.5 (DIN_2)
unnamed: D16.3 (DOUT), D17.1 (DIN_1), D17.5 (DIN_2)
unnamed: D17.3 (DOUT), D18.1 (DIN_1), D18.5 (DIN_2)
unnamed: D18.3 (DOUT), D19.1 (DIN_1), D19.5 (DIN_2)
unnamed: D19.3 (DOUT), D20.1 (DIN_1), D20.5 (DIN_2)
unnamed: D20.3 (DOUT), D21.1 (DIN_1), D21.5 (DIN_2)
unnamed: D21.3 (DOUT), D22.1 (DIN_1), D22.5 (DIN_2)
unnamed: D22.3 (DOUT), D23.1 (DIN_1), D23.5 (DIN_2)
unnamed: D23.3 (DOUT), D24.1 (DIN_1), D24.5 (DIN_2)
unnamed: D24.3 (DOUT), D25.1 (DIN_1), D25.5 (DIN_2)
unnamed: D25.3 (DOUT), D26.1 (DIN_1), D26.5 (DIN_2)
unnamed: D26.3 (DOUT), D27.1 (DIN_1), D27.5 (DIN_2)
unnamed: D27.3 (DOUT), D28.1 (DIN_1), D28.5 (DIN_2)
unnamed: D28.3 (DOUT), D29.1 (DIN_1), D29.5 (DIN_2)
unnamed: D29.3 (DOUT), D30.1 (DIN_1), D30.5 (DIN_2)
unnamed: D30.3 (DOUT), D31.1 (DIN_1), D31.5 (DIN_2)
unnamed: D31.3 (DOUT), D32.1 (DIN_1), D32.5 (DIN_2)
unnamed: D32.3 (DOUT), D33.1 (DIN_1), D33.5 (DIN_2)
unnamed: KEY1.1 (Pin_1_1), U1.8 (ELE0)
unnamed: KEY2.1 (Pin_1_1), U1.9 (ELE1)
unnamed: KEY3.1 (Pin_1_1), U1.10 (ELE2)
unnamed: KEY4.1 (Pin_1_1), U1.11 (ELE3)
unnamed: KEY5.1 (Pin_1_1), U1.12 (LED0/ELE4)
unnamed: KEY6.1 (Pin_1_1), U1.13 (LED1/ELE5)
unnamed: KEY7.1 (Pin_1_1), U1.14 (LED2/ELE6)
unnamed: KEY8.1 (Pin_1_1), U1.15 (LED3/ELE7)
unnamed: KEY9.1 (Pin_1_1), U1.16 (LED4/ELE8)
unnamed: KEY10.1 (Pin_1_1), U1.17 (LED5/ELE9)
unnamed: KEY11.1 (Pin_1_1), U1.18 (LED6/ELE10)
unnamed: KEY12.1 (Pin_1_1), U1.19 (LED7/ELE11)
unnamed: KEY13.1 (Pin_1_1), U2.8 (ELE0)
unnamed: KEY14.1 (Pin_1_1), U2.9 (ELE1)
unnamed: KEY15.1 (Pin_1_1), U2.10 (ELE2)
unnamed: KEY16.1 (Pin_1_1), U2.11 (ELE3)
unnamed: KEY17.1 (Pin_1_1), U2.12 (LED0/ELE4)
unnamed: KEY18.1 (Pin_1_1), U2.13 (LED1/ELE5)
unnamed: KEY19.1 (Pin_1_1), U2.14 (LED2/ELE6)
unnamed: KEY20.1 (Pin_1_1), U2.15 (LED3/ELE7)
unnamed: KEY21.1 (Pin_1_1), U2.16 (LED4/ELE8)
unnamed: KEY22.1 (Pin_1_1), U2.17 (LED5/ELE9)
unnamed: KEY23.1 (Pin_1_1), U2.18 (LED6/ELE10)
unnamed: KEY24.1 (Pin_1_1), U2.19 (LED7/ELE11)
unnamed: KEY25.1 (Pin_1_1), U3.8 (ELE0)
unnamed: KEY26.1 (Pin_1_1), U3.9 (ELE1)
unnamed: KEY27.1 (Pin_1_1), U3.10 (ELE2)
unnamed: KEY28.1 (Pin_1_1), U3.11 (ELE3)
unnamed: KEY29.1 (Pin_1_1), U3.12 (LED0/ELE4)
unnamed: KEY30.1 (Pin_1_1), U3.13 (LED1/ELE5)
unnamed: KEY31.1 (Pin_1_1), U3.14 (LED2/ELE6)
unnamed: KEY32.1 (Pin_1_1), U3.15 (LED3/ELE7)
SCL: J1.4, U1.2 (SCL), U2.2 (SCL), U3.2 (SCL)
SDA: J1.5, U1.3 (SDA), U2.3 (SDA), U3.3 (SDA), U3.4 (ADDR)

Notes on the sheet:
Mounting Screws
ADDR=0x5C
ADDR=0x5A
ADDR=0x5B

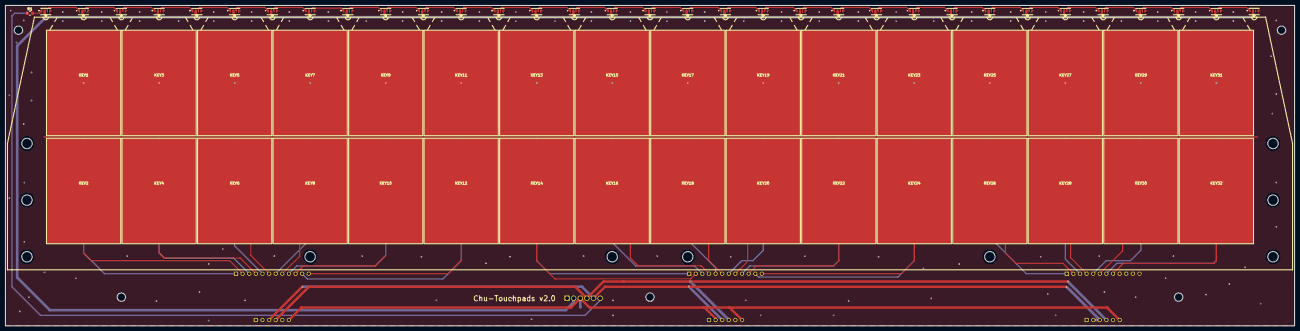
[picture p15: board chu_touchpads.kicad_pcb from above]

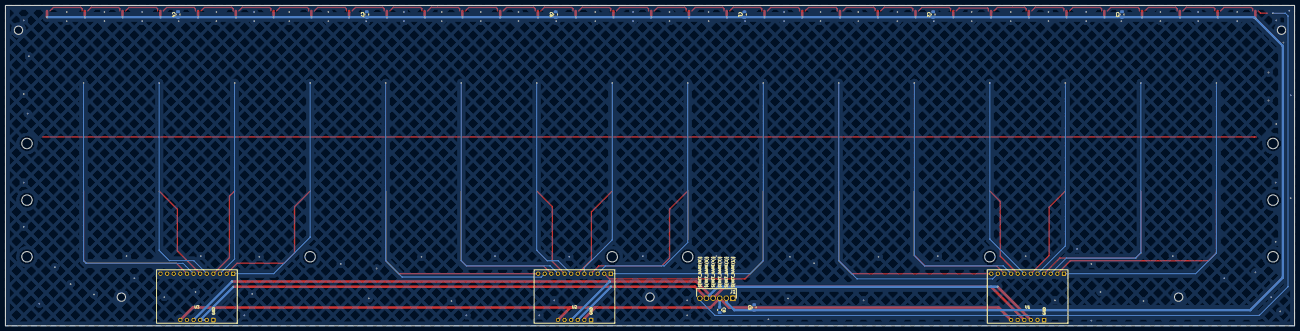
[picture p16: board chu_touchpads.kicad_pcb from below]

Board: 2 copper layers, 495.0 x 123.0 mm, 84 parts (12 on the bottom side), 71 nets.

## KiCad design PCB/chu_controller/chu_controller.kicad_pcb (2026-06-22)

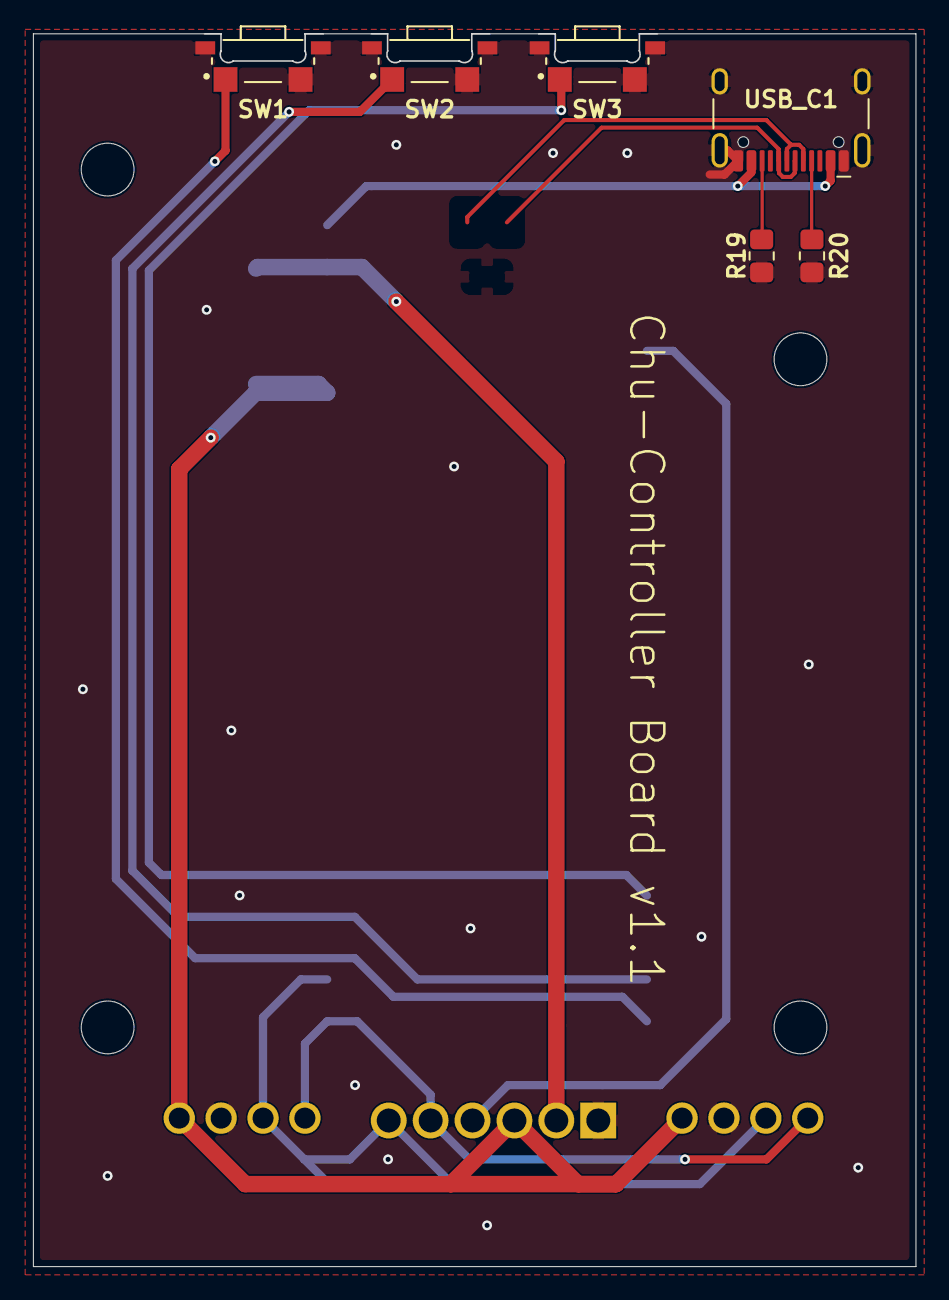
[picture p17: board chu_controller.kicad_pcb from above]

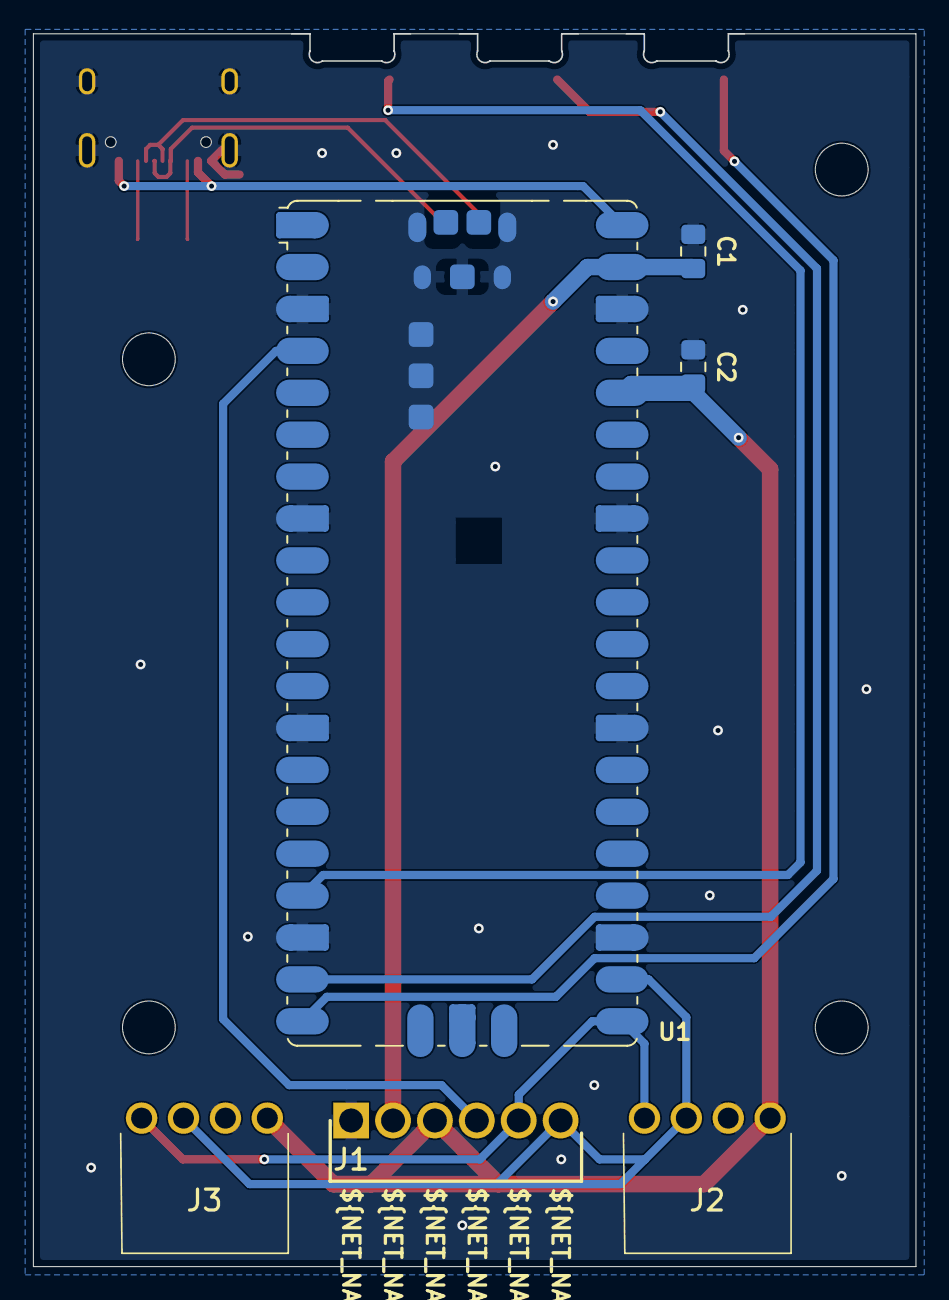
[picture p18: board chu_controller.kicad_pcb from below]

Board: 2 copper layers, 53.5 x 74.7 mm, 16 parts (6 on the bottom side), 14 nets.

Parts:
C1, C2: 1uF; C_0805_2012Metric_Pad1.18x1.45mm_HandSolder
J1: Conn_01x06_Pin; SHDRRA6W88P0X254_1X6_1524X254X610P
J2, J3: Conn_01x04_Pin; 6404554
R19, R20: 5K1; R_0805_2012Metric_Pad1.20x1.40mm_HandSolder
SCR1, SCR2, SCR3, SCR4: MountingHole_3.2mm_M3
SW1, SW2, SW3: SW_SPST; SW_EVQ-P46B3M
U1: RaspberryPi_Pico_Testing_pins; RaspberryPi_Pico_SMD
USB_C1: USB_C_Receptacle_HCTL_HC-TYPE-C-16P-01A

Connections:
+3V3: C2.1, J1.3, J2.1, J3.1, U1.36 (3V3)
+5V: C1.1, J1.2, U1.39 (VSYS)
/LED_Data: J1.4, U1.4 (GPIO2)
/SCL: J1.6, J2.3, J3.3, U1.22 (GPIO17)
/SDA: J1.5, J2.4, J3.4, U1.21 (GPIO16)
GND: C1.2, C2.2, J1.1, J2.2, J3.2, R19.2, R20.2, SW1.2 (B), SW1.SHIELD, SW2.2 (B), SW2.SHIELD, SW3.2 (B), SW3.SHIELD, U1.3 (GND), U1.8 (GND), U1.13 (GND), U1.18 (GND), U1.23 (GND), U1.28 (GND), U1.33 (AGND), U1.38 (GND), U1.TP1 (USB_GND), USB_C1.1 (GND), USB_C1.12 (GND), USB_C1.13 (SHIELD)
unnamed: SW1.1 (A), U1.20 (GPIO15)
unnamed: SW2.1 (A), U1.19 (GPIO14)
unnamed: SW3.1 (A), U1.17 (GPIO13)
unnamed: U1.TP2 (USB_DM), USB_C1.5 (DN2), USB_C1.7 (DN1)
unnamed: U1.TP3 (USB_DP), USB_C1.6 (DP1), USB_C1.8 (DP2)
unnamed: R20.1, USB_C1.4 (CC1)
unnamed: R19.1, USB_C1.10 (CC2)
VBUS: U1.40 (VBUS), USB_C1.2 (VBUS), USB_C1.11 (VBUS)

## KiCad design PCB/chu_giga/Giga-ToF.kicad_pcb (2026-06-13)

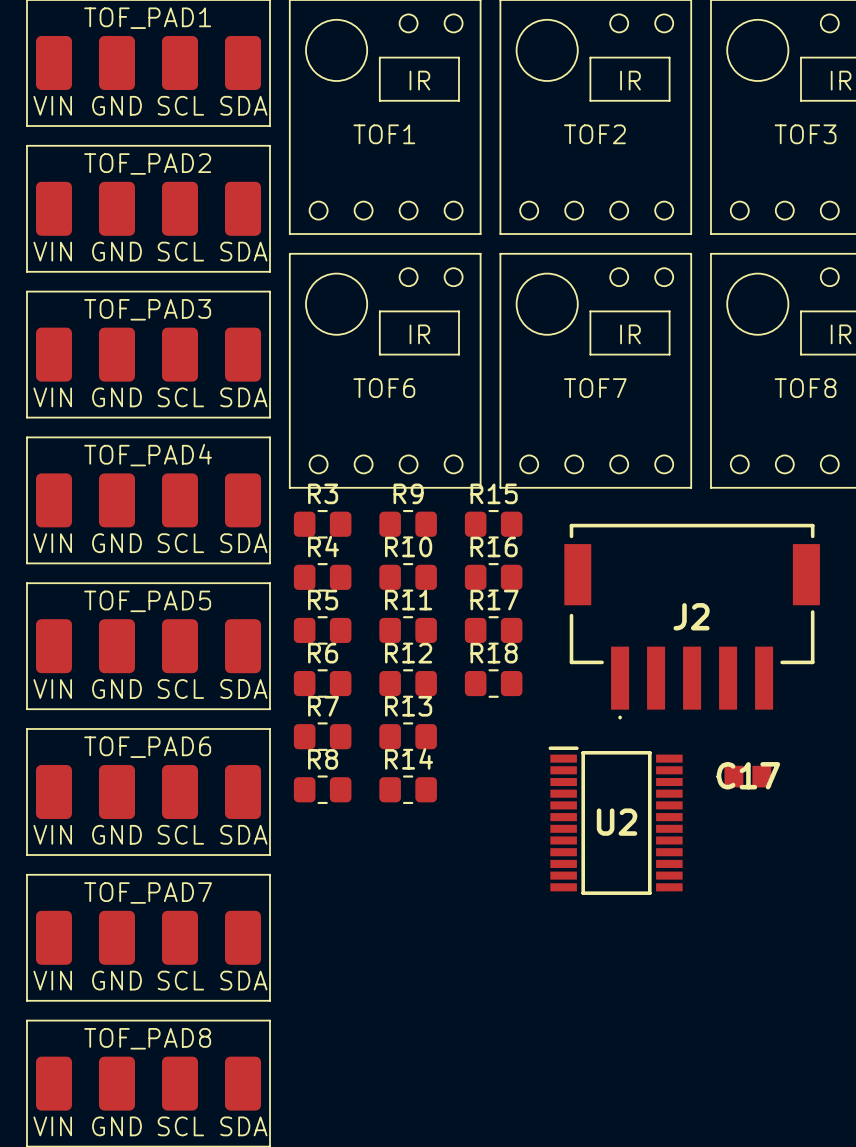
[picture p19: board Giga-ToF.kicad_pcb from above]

Board: 2 copper layers, 35 parts (0 on the bottom side), 21 nets, no tracks yet.

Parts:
C17: 0.1uF; TMCP1E104MTRF
J2: Conn_01x05_Pin; 17754695
R3, R4, R5, R6, R7, R8, R9, R10, R11, R12, R13, R14, R15, R16, R17, R18: 5K1; R_0805_2012Metric_Pad1.20x1.40mm_HandSolder
TOF1, TOF2, TOF3, TOF4, TOF5, TOF6, TOF7, TOF8: GY530 ToF Sensor board
TOF_PAD1, TOF_PAD2, TOF_PAD3, TOF_PAD4, TOF_PAD5, TOF_PAD6, TOF_PAD7, TOF_PAD8: ToF Wiring Pad
U2: TCA9548APWR; SOP65P640X120-24N

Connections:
+3V3: C17.1, J2.1, R3.1, R4.1, R5.1, R6.1, R7.1, R8.1, R9.1, R10.1, R11.1, R12.1, R13.1, R14.1, R15.1, R16.1, R17.1, R18.1, TOF_PAD1.1 (VIN), TOF_PAD2.1 (VIN), TOF_PAD3.1 (VIN), TOF_PAD4.1 (VIN), TOF_PAD5.1 (VIN), TOF_PAD6.1 (VIN), TOF_PAD7.1 (VIN), TOF_PAD8.1 (VIN), U2.24 (VCC)
/Controller/SCL: J2.3, U2.22 (SCL)
/Controller/SDA: J2.4, U2.23 (SDA)
/Controller/ToF_Reset: J2.5, U2.3 (~RESET)
/Time-Of-Flight sensors/SCL_1: R3.2, TOF_PAD1.3 (SCL), U2.5 (SC0)
/Time-Of-Flight sensors/SCL_2: R5.2, TOF_PAD2.3 (SCL), U2.7 (SC1)
/Time-Of-Flight sensors/SCL_3: R7.2, TOF_PAD3.3 (SCL), U2.9 (SC2)
/Time-Of-Flight sensors/SCL_4: R9.2, TOF_PAD4.3 (SCL), U2.11 (SC3)
/Time-Of-Flight sensors/SCL_5: R11.2, TOF_PAD5.3 (SCL), U2.14 (SC4)
/Time-Of-Flight sensors/SCL_6: R13.2, TOF_PAD6.3 (SCL), U2.16 (SC5)
/Time-Of-Flight sensors/SCL_7: R15.2, TOF_PAD7.3 (SCL), U2.18 (SC6)
/Time-Of-Flight sensors/SCL_8: R17.2, TOF_PAD8.3 (SCL), U2.20 (SC7)
/Time-Of-Flight sensors/SDA_1: R4.2, TOF_PAD1.4 (SDA), U2.4 (SD0)
/Time-Of-Flight sensors/SDA_2: R6.2, TOF_PAD2.4 (SDA), U2.6 (SD1)
/Time-Of-Flight sensors/SDA_3: R8.2, TOF_PAD3.4 (SDA), U2.8 (SD2)
/Time-Of-Flight sensors/SDA_4: R10.2, TOF_PAD4.4 (SDA), U2.10 (SD3)
/Time-Of-Flight sensors/SDA_5: R12.2, TOF_PAD5.4 (SDA), U2.13 (SD4)
/Time-Of-Flight sensors/SDA_6: R14.2, TOF_PAD6.4 (SDA), U2.15 (SD5)
/Time-Of-Flight sensors/SDA_7: R16.2, TOF_PAD7.4 (SDA), U2.17 (SD6)
/Time-Of-Flight sensors/SDA_8: R18.2, TOF_PAD8.4 (SDA), U2.19 (SD7)
GND: C17.2, J2.2, TOF_PAD1.2 (GND), TOF_PAD2.2 (GND), TOF_PAD3.2 (GND), TOF_PAD4.2 (GND), TOF_PAD5.2 (GND), TOF_PAD6.2 (GND), TOF_PAD7.2 (GND), TOF_PAD8.2 (GND), U2.1 (A0), U2.2 (A1), U2.12 (GND), U2.21 (A2)

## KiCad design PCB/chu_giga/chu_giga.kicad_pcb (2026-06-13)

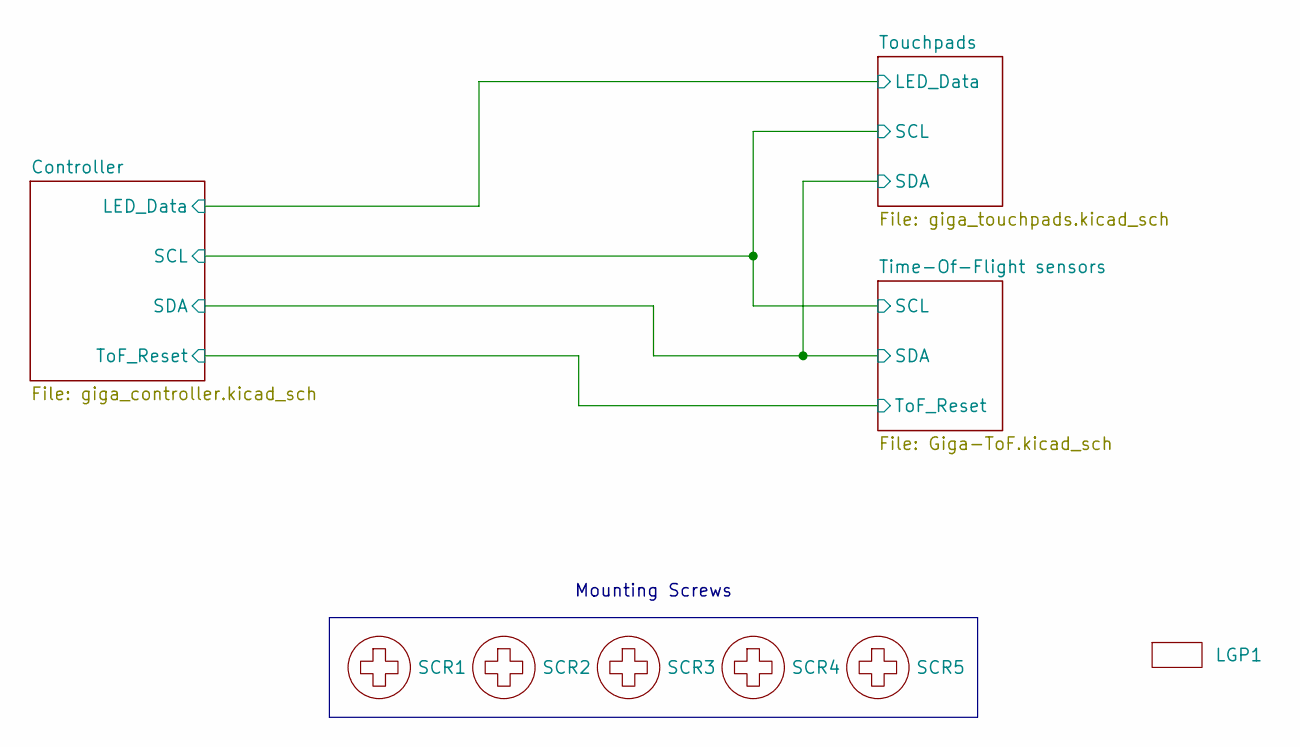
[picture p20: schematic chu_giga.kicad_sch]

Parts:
LGP1: LGP_new
SCR1, SCR2, SCR3, SCR4, SCR5: MountingHole_3.2mm_M3

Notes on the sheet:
Mounting Screws

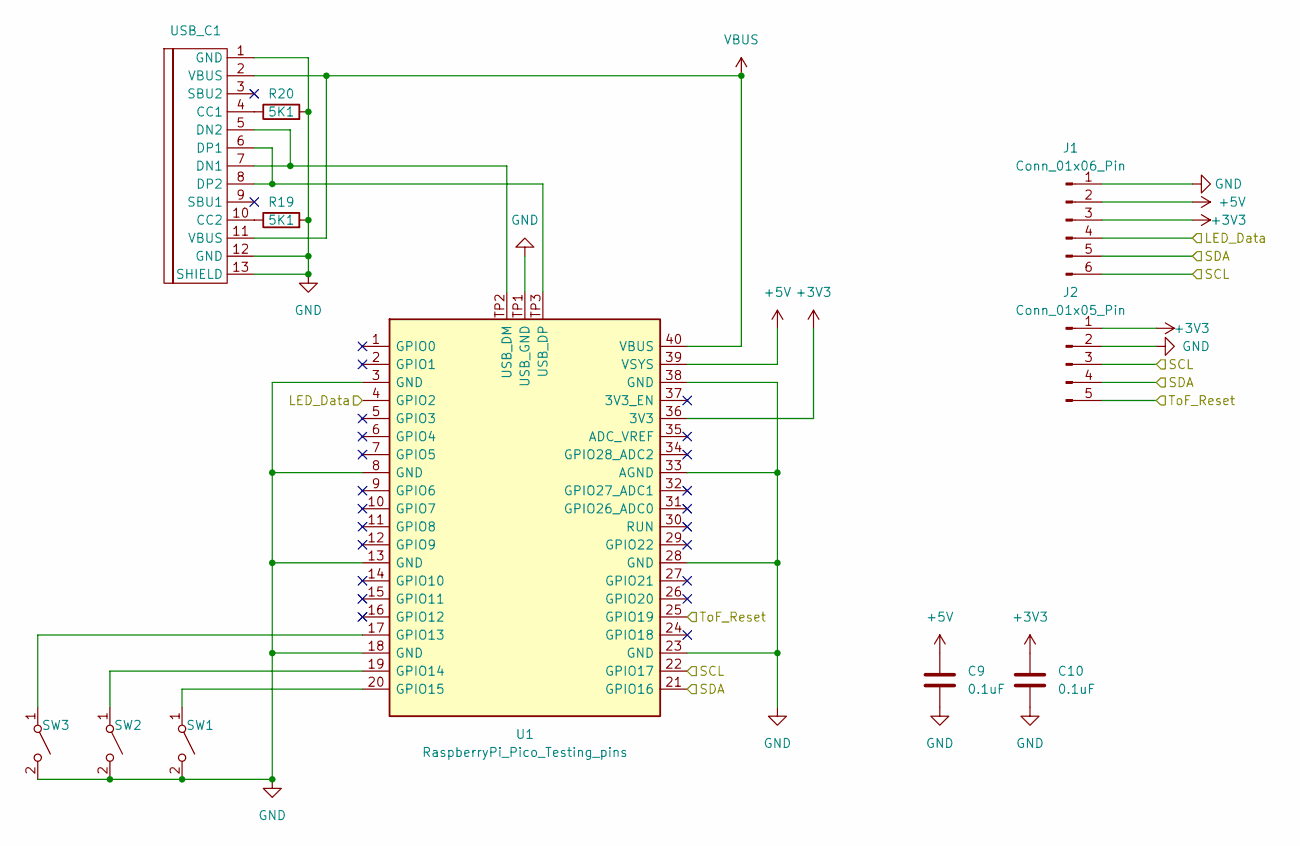
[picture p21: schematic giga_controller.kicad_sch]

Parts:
C9, C10: 0.1uF; TMCP1E104MTRF
J1: Conn_01x06_Pin; 17754696
J2: Conn_01x05_Pin; 17754695
R19, R20: 5K1; R_0805_2012Metric_Pad1.20x1.40mm_HandSolder
SW1, SW2, SW3: SW_SPST; SW_EVQ-P46B3M
U1: RaspberryPi_Pico_Testing_pins; RaspberryPi_Pico_SMD
USB_C1: USB_C_Receptacle_HCTL_HC-TYPE-C-16P-01A

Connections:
+3V3: C10.1, J1.3, J2.1, U1.36 (3V3); also elsewhere on the board
+5V: C9.1, J1.2, U1.39 (VSYS); also elsewhere on the board
/Controller/LED_Data: J1.4, U1.4 (GPIO2); also elsewhere on the board
/Controller/SCL: J1.6, J2.3, U1.22 (GPIO17); also elsewhere on the board
/Controller/SDA: J1.5, J2.4, U1.21 (GPIO16); also elsewhere on the board
/Controller/ToF_Reset: J2.5, U1.25 (GPIO19); also elsewhere on the board
GND: C9.2, C10.2, J1.1, J2.2, R19.2, R20.2, SW1.2 (B), SW2.2 (B), SW3.2 (B), U1.3 (GND), U1.8 (GND), U1.13 (GND), U1.18 (GND), U1.23 (GND), U1.28 (GND), U1.33 (AGND), U1.38 (GND), U1.TP1 (USB_GND), USB_C1.1 (GND), USB_C1.12 (GND), USB_C1.13 (SHIELD); also elsewhere on the board
unnamed: SW1.1 (A), U1.20 (GPIO15)
unnamed: SW2.1 (A), U1.19 (GPIO14)
unnamed: SW3.1 (A), U1.17 (GPIO13)
unnamed: U1.TP2 (USB_DM), USB_C1.5 (DN2), USB_C1.7 (DN1)
unnamed: U1.TP3 (USB_DP), USB_C1.6 (DP1), USB_C1.8 (DP2)
unnamed: R20.1, USB_C1.4 (CC1)
unnamed: R19.1, USB_C1.10 (CC2)
VBUS: U1.40 (VBUS), USB_C1.2 (VBUS), USB_C1.11 (VBUS)

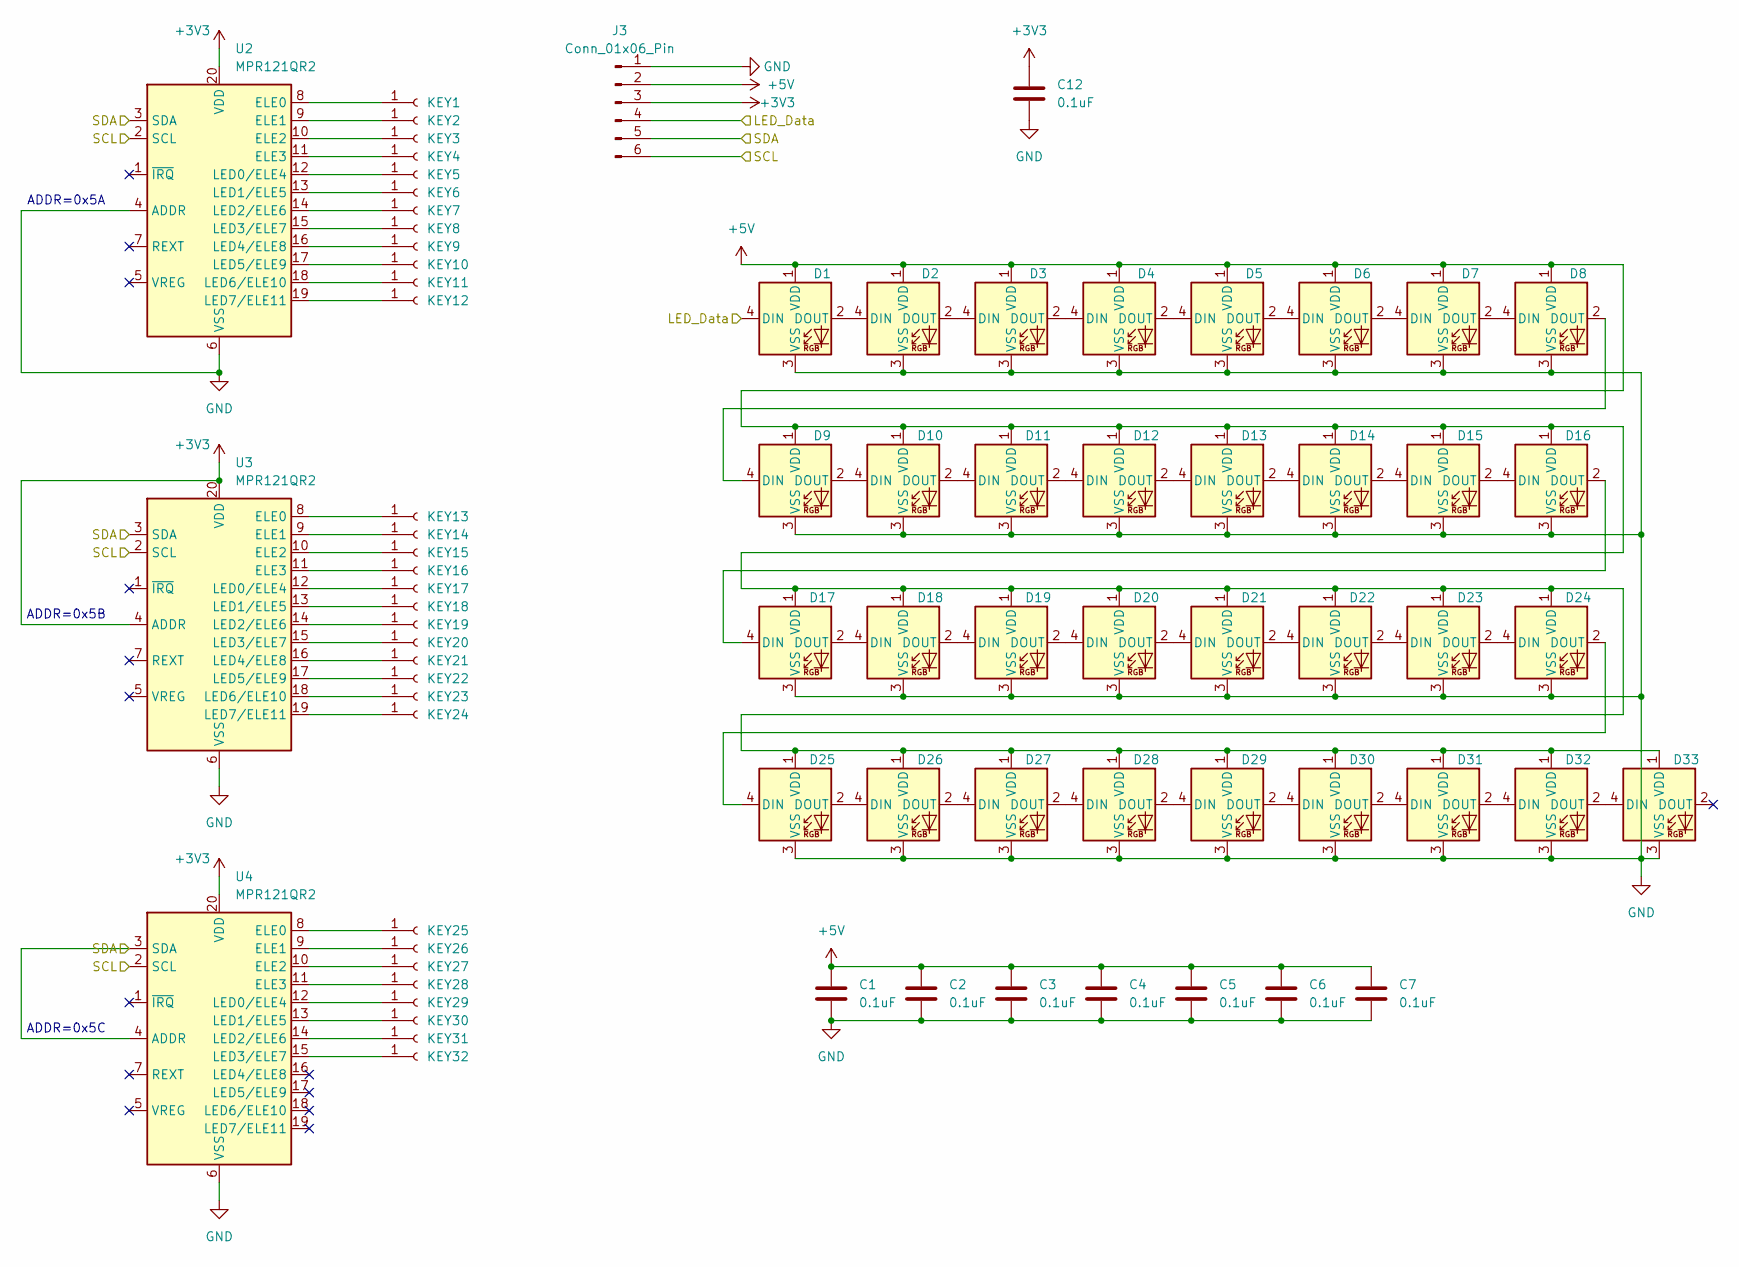
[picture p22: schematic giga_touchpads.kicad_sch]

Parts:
C1, C2, C3, C4, C5, C6, C7, C12: 0.1uF; TMCP1E104MTRF
D1, D2, D3, D4, D5, D6, D7, D8, D9, D10, D11, D12, D13, D14, D15, D16, D17, D18, D19, D20, D21, D22, D23, D24, D25, D26, D27, D28, D29, D30, D31, D32, D33: WS2812B; INPI42TASPRPGPB
J3: Conn_01x06_Pin; 17754696
KEY1, KEY2, KEY3, KEY4, KEY5, KEY6, KEY7, KEY8, KEY9, KEY10, KEY11, KEY12, KEY13, KEY14, KEY15, KEY16, KEY17, KEY18, KEY19, KEY20, KEY21, KEY22, KEY23, KEY24, KEY25, KEY26, KEY27, KEY28, KEY29, KEY30, KEY31, KEY32: Conn_01x01_Socket; Capacitive_Touchpad_405x285
U2, U3, U4: MPR121QR2; MPR121_BOARD

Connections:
+3V3: C12.1, J3.3, U2.20 (VDD), U3.4 (ADDR), U3.20 (VDD), U4.20 (VDD); also elsewhere on the board
+5V: C1.1, C2.1, C3.1, C4.1, C5.1, C6.1, C7.1, D1.1 (VDD), D2.1 (VDD), D3.1 (VDD), D4.1 (VDD), D5.1 (VDD), D6.1 (VDD), D7.1 (VDD), D8.1 (VDD), D9.1 (VDD), D10.1 (VDD), D11.1 (VDD), D12.1 (VDD), D13.1 (VDD), D14.1 (VDD), D15.1 (VDD), D16.1 (VDD), D17.1 (VDD), D18.1 (VDD), D19.1 (VDD), D20.1 (VDD), D21.1 (VDD), D22.1 (VDD), D23.1 (VDD), D24.1 (VDD), D25.1 (VDD), D26.1 (VDD), D27.1 (VDD), D28.1 (VDD), D29.1 (VDD), D30.1 (VDD), D31.1 (VDD), D32.1 (VDD), D33.1 (VDD), J3.2; also elsewhere on the board
/Controller/LED_Data: D1.4 (DIN), J3.4; also elsewhere on the board
/Controller/SCL: J3.6, U2.2 (SCL), U3.2 (SCL), U4.2 (SCL); also elsewhere on the board
/Controller/SDA: J3.5, U2.3 (SDA), U3.3 (SDA), U4.3 (SDA), U4.4 (ADDR); also elsewhere on the board
GND: C1.2, C2.2, C3.2, C4.2, C5.2, C6.2, C7.2, C12.2, D1.3 (VSS), D2.3 (VSS), D3.3 (VSS), D4.3 (VSS), D5.3 (VSS), D6.3 (VSS), D7.3 (VSS), D8.3 (VSS), D9.3 (VSS), D10.3 (VSS), D11.3 (VSS), D12.3 (VSS), D13.3 (VSS), D14.3 (VSS), D15.3 (VSS), D16.3 (VSS), D17.3 (VSS), D18.3 (VSS), D19.3 (VSS), D20.3 (VSS), D21.3 (VSS), D22.3 (VSS), D23.3 (VSS), D24.3 (VSS), D25.3 (VSS), D26.3 (VSS), D27.3 (VSS), D28.3 (VSS), D29.3 (VSS), D30.3 (VSS), D31.3 (VSS), D32.3 (VSS), D33.3 (VSS), J3.1, U2.4 (ADDR), U2.6 (VSS), U3.6 (VSS), U4.6 (VSS); also elsewhere on the board
unnamed: D1.2 (DOUT), D2.4 (DIN)
unnamed: D2.2 (DOUT), D3.4 (DIN)
unnamed: D3.2 (DOUT), D4.4 (DIN)
unnamed: D4.2 (DOUT), D5.4 (DIN)
unnamed: D5.2 (DOUT), D6.4 (DIN)
unnamed: D6.2 (DOUT), D7.4 (DIN)
unnamed: D7.2 (DOUT), D8.4 (DIN)
unnamed: D8.2 (DOUT), D9.4 (DIN)
unnamed: D9.2 (DOUT), D10.4 (DIN)
unnamed: D10.2 (DOUT), D11.4 (DIN)
unnamed: D11.2 (DOUT), D12.4 (DIN)
unnamed: D12.2 (DOUT), D13.4 (DIN)
unnamed: D13.2 (DOUT), D14.4 (DIN)
unnamed: D14.2 (DOUT), D15.4 (DIN)
unnamed: D15.2 (DOUT), D16.4 (DIN)
unnamed: D16.2 (DOUT), D17.4 (DIN)
unnamed: D17.2 (DOUT), D18.4 (DIN)
unnamed: D18.2 (DOUT), D19.4 (DIN)
unnamed: D19.2 (DOUT), D20.4 (DIN)
unnamed: D20.2 (DOUT), D21.4 (DIN)
unnamed: D21.2 (DOUT), D22.4 (DIN)
unnamed: D22.2 (DOUT), D23.4 (DIN)
unnamed: D23.2 (DOUT), D24.4 (DIN)
unnamed: D24.2 (DOUT), D25.4 (DIN)
unnamed: D25.2 (DOUT), D26.4 (DIN)
unnamed: D26.2 (DOUT), D27.4 (DIN)
unnamed: D27.2 (DOUT), D28.4 (DIN)
unnamed: D28.2 (DOUT), D29.4 (DIN)
unnamed: D29.2 (DOUT), D30.4 (DIN)
unnamed: D30.2 (DOUT), D31.4 (DIN)
unnamed: D31.2 (DOUT), D32.4 (DIN)
unnamed: D32.2 (DOUT), D33.4 (DIN)
unnamed: KEY1.1 (Pin_1_1), U2.8 (ELE0)
unnamed: KEY2.1 (Pin_1_1), U2.9 (ELE1)
unnamed: KEY3.1 (Pin_1_1), U2.10 (ELE2)
unnamed: KEY4.1 (Pin_1_1), U2.11 (ELE3)
unnamed: KEY5.1 (Pin_1_1), U2.12 (LED0/ELE4)
unnamed: KEY6.1 (Pin_1_1), U2.13 (LED1/ELE5)
unnamed: KEY7.1 (Pin_1_1), U2.14 (LED2/ELE6)
unnamed: KEY8.1 (Pin_1_1), U2.15 (LED3/ELE7)
unnamed: KEY9.1 (Pin_1_1), U2.16 (LED4/ELE8)
unnamed: KEY10.1 (Pin_1_1), U2.17 (LED5/ELE9)
unnamed: KEY11.1 (Pin_1_1), U2.18 (LED6/ELE10)
unnamed: KEY12.1 (Pin_1_1), U2.19 (LED7/ELE11)
unnamed: KEY13.1 (Pin_1_1), U3.8 (ELE0)
unnamed: KEY14.1 (Pin_1_1), U3.9 (ELE1)
unnamed: KEY15.1 (Pin_1_1), U3.10 (ELE2)
unnamed: KEY16.1 (Pin_1_1), U3.11 (ELE3)
unnamed: KEY17.1 (Pin_1_1), U3.12 (LED0/ELE4)
unnamed: KEY18.1 (Pin_1_1), U3.13 (LED1/ELE5)
unnamed: KEY19.1 (Pin_1_1), U3.14 (LED2/ELE6)
unnamed: KEY20.1 (Pin_1_1), U3.15 (LED3/ELE7)
unnamed: KEY21.1 (Pin_1_1), U3.16 (LED4/ELE8)
unnamed: KEY22.1 (Pin_1_1), U3.17 (LED5/ELE9)
unnamed: KEY23.1 (Pin_1_1), U3.18 (LED6/ELE10)
unnamed: KEY24.1 (Pin_1_1), U3.19 (LED7/ELE11)
unnamed: KEY25.1 (Pin_1_1), U4.8 (ELE0)
unnamed: KEY26.1 (Pin_1_1), U4.9 (ELE1)
unnamed: KEY27.1 (Pin_1_1), U4.10 (ELE2)
unnamed: KEY28.1 (Pin_1_1), U4.11 (ELE3)
unnamed: KEY29.1 (Pin_1_1), U4.12 (LED0/ELE4)
unnamed: KEY30.1 (Pin_1_1), U4.13 (LED1/ELE5)
unnamed: KEY31.1 (Pin_1_1), U4.14 (LED2/ELE6)
unnamed: KEY32.1 (Pin_1_1), U4.15 (LED3/ELE7)

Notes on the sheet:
ADDR=0x5C
ADDR=0x5A
ADDR=0x5B

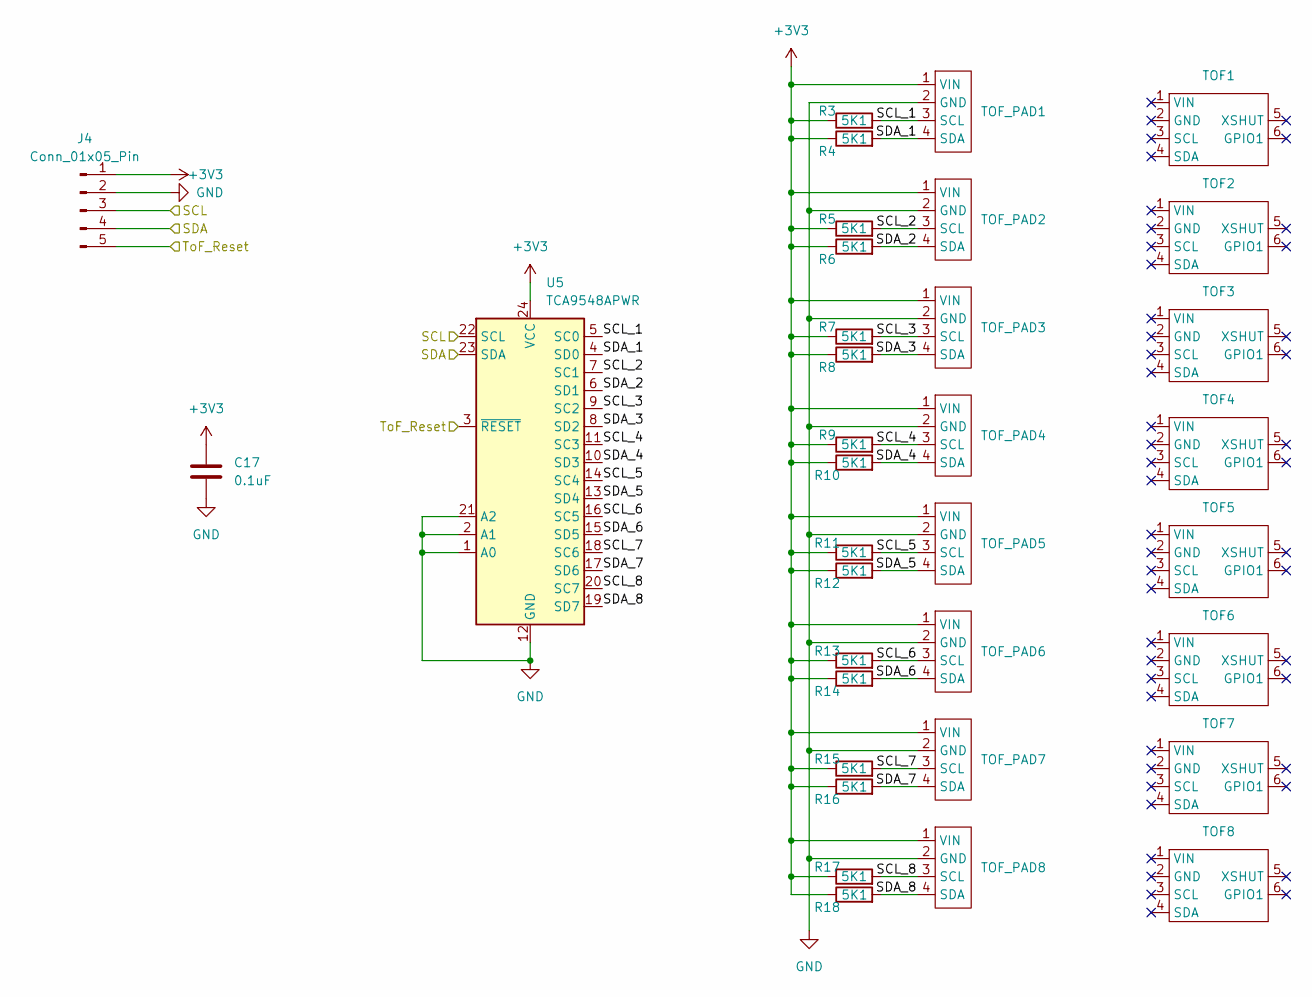
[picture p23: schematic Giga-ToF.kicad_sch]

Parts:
C17: 0.1uF; TMCP1E104MTRF
J4: Conn_01x05_Pin; 17754695
R3, R4, R5, R6, R7, R8, R9, R10, R11, R12, R13, R14, R15, R16, R17, R18: 5K1; R_0805_2012Metric_Pad1.20x1.40mm_HandSolder
TOF1, TOF2, TOF3, TOF4, TOF5, TOF6, TOF7, TOF8: GY530 ToF Sensor board
TOF_PAD1, TOF_PAD2, TOF_PAD3, TOF_PAD4, TOF_PAD5, TOF_PAD6, TOF_PAD7, TOF_PAD8: ToF Wiring Pad
U5: TCA9548APWR; SOP65P640X120-24N

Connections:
+3V3: C17.1, J4.1, R3.1, R4.1, R5.1, R6.1, R7.1, R8.1, R9.1, R10.1, R11.1, R12.1, R13.1, R14.1, R15.1, R16.1, R17.1, R18.1, TOF_PAD1.1 (VIN), TOF_PAD2.1 (VIN), TOF_PAD3.1 (VIN), TOF_PAD4.1 (VIN), TOF_PAD5.1 (VIN), TOF_PAD6.1 (VIN), TOF_PAD7.1 (VIN), TOF_PAD8.1 (VIN), U5.24 (VCC); also elsewhere on the board
/Controller/SCL: J4.3, U5.22 (SCL); also elsewhere on the board
/Controller/SDA: J4.4, U5.23 (SDA); also elsewhere on the board
/Controller/ToF_Reset: J4.5, U5.3 (~RESET); also elsewhere on the board
/Time-Of-Flight sensors/SCL_1: R3.2, TOF_PAD1.3 (SCL), U5.5 (SC0)
/Time-Of-Flight sensors/SCL_2: R5.2, TOF_PAD2.3 (SCL), U5.7 (SC1)
/Time-Of-Flight sensors/SCL_3: R7.2, TOF_PAD3.3 (SCL), U5.9 (SC2)
/Time-Of-Flight sensors/SCL_4: R9.2, TOF_PAD4.3 (SCL), U5.11 (SC3)
/Time-Of-Flight sensors/SCL_5: R11.2, TOF_PAD5.3 (SCL), U5.14 (SC4)
/Time-Of-Flight sensors/SCL_6: R13.2, TOF_PAD6.3 (SCL), U5.16 (SC5)
/Time-Of-Flight sensors/SCL_7: R15.2, TOF_PAD7.3 (SCL), U5.18 (SC6)
/Time-Of-Flight sensors/SCL_8: R17.2, TOF_PAD8.3 (SCL), U5.20 (SC7)
/Time-Of-Flight sensors/SDA_1: R4.2, TOF_PAD1.4 (SDA), U5.4 (SD0)
/Time-Of-Flight sensors/SDA_2: R6.2, TOF_PAD2.4 (SDA), U5.6 (SD1)
/Time-Of-Flight sensors/SDA_3: R8.2, TOF_PAD3.4 (SDA), U5.8 (SD2)
/Time-Of-Flight sensors/SDA_4: R10.2, TOF_PAD4.4 (SDA), U5.10 (SD3)
/Time-Of-Flight sensors/SDA_5: R12.2, TOF_PAD5.4 (SDA), U5.13 (SD4)
/Time-Of-Flight sensors/SDA_6: R14.2, TOF_PAD6.4 (SDA), U5.15 (SD5)
/Time-Of-Flight sensors/SDA_7: R16.2, TOF_PAD7.4 (SDA), U5.17 (SD6)
/Time-Of-Flight sensors/SDA_8: R18.2, TOF_PAD8.4 (SDA), U5.19 (SD7)
GND: C17.2, J4.2, TOF_PAD1.2 (GND), TOF_PAD2.2 (GND), TOF_PAD3.2 (GND), TOF_PAD4.2 (GND), TOF_PAD5.2 (GND), TOF_PAD6.2 (GND), TOF_PAD7.2 (GND), TOF_PAD8.2 (GND), U5.1 (A0), U5.2 (A1), U5.12 (GND), U5.21 (A2); also elsewhere on the board

Board: 2 copper layers, 129 parts (12 on the bottom side), 95 nets, no tracks yet.

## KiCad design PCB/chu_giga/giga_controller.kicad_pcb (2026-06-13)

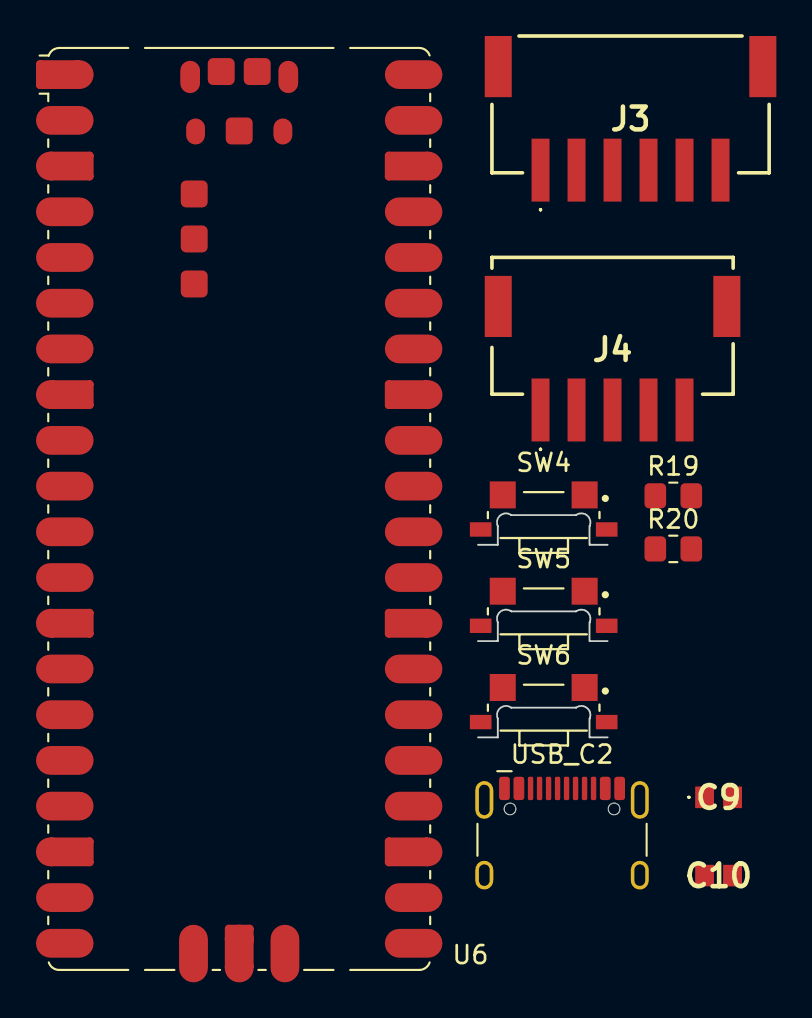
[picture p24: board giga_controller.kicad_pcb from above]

Board: 2 copper layers, 11 parts (0 on the bottom side), 15 nets, no tracks yet.

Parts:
C9, C10: 0.1uF; TMCP1E104MTRF
J3: Conn_01x06_Pin; 17754696
J4: Conn_01x05_Pin; 17754695
R19, R20: 5K1; R_0805_2012Metric_Pad1.20x1.40mm_HandSolder
SW4, SW5, SW6: SW_SPST; SW_EVQ-P46B3M
U6: RaspberryPi_Pico_Testing_pins; RaspberryPi_Pico_SMD
USB_C2: USB_C_Receptacle_HCTL_HC-TYPE-C-16P-01A

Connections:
+3V3: C10.1, J3.3, J4.1, U6.36 (3V3)
+5V: C9.1, J3.2, U6.39 (VSYS)
/Controller/LED_Data: J3.4, U6.4 (GPIO2)
/Controller/SCL: J3.6, J4.3, U6.22 (GPIO17)
/Controller/SDA: J3.5, J4.4, U6.21 (GPIO16)
/Controller/ToF_Reset: J4.5, U6.25 (GPIO19)
GND: C9.2, C10.2, J3.1, J4.2, R19.2, R20.2, SW4.2 (B), SW5.2 (B), SW6.2 (B), U6.3 (GND), U6.8 (GND), U6.13 (GND), U6.18 (GND), U6.23 (GND), U6.28 (GND), U6.33 (AGND), U6.38 (GND), U6.TP1 (USB_GND), USB_C2.1 (GND), USB_C2.12 (GND), USB_C2.13 (SHIELD)
unnamed: SW4.1 (A), U6.20 (GPIO15)
unnamed: SW5.1 (A), U6.19 (GPIO14)
unnamed: SW6.1 (A), U6.17 (GPIO13)
unnamed: U6.TP2 (USB_DM), USB_C2.5 (DN2), USB_C2.7 (DN1)
unnamed: U6.TP3 (USB_DP), USB_C2.6 (DP1), USB_C2.8 (DP2)
unnamed: R20.1, USB_C2.4 (CC1)
unnamed: R19.1, USB_C2.10 (CC2)
VBUS: U6.40 (VBUS), USB_C2.2 (VBUS), USB_C2.11 (VBUS)

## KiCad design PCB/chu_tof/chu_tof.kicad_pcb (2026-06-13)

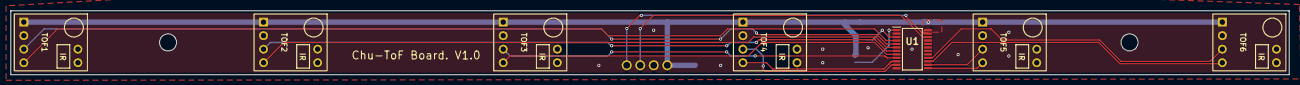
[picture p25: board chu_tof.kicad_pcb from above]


Board: 2 copper layers, 240.0 x 12.0 mm, 14 parts (5 on the bottom side), 18 nets.

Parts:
A0_0, A0_1: SolderJumper_2_Open; SolderJumper-2_P1.3mm_Open_RoundedPad1.0x1.5mm
C1: 1uF; C_0805_2012Metric_Pad1.18x1.45mm_HandSolder
J1: Conn_01x04_Pin; 6404554
R1: 5K1; R_0805_2012Metric_Pad1.20x1.40mm_HandSolder
SCR1, SCR2: MountingHole_3.2mm_M3
TOF1, TOF2, TOF3, TOF4, TOF5, TOF6: GY530 ToF Sensor board
U1: TCA9548APWR; SOP65P640X120-24N

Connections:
+3V3: A0_1.2 (B), C1.1, J1.1, R1.1, TOF1.1 (VIN), TOF2.1 (VIN), TOF3.1 (VIN), TOF4.1 (VIN), TOF5.1 (VIN), TOF6.1 (VIN), U1.24 (VCC)
/SCL: J1.3, U1.22 (SCL)
/SCL_1: TOF1.3 (SCL), U1.5 (SC0)
/SCL_2: TOF2.3 (SCL), U1.7 (SC1)
/SCL_3: TOF3.3 (SCL), U1.9 (SC2)
/SCL_4: TOF4.3 (SCL), U1.11 (SC3)
/SCL_5: TOF5.3 (SCL), U1.14 (SC4)
/SCL_6: TOF6.3 (SCL), U1.16 (SC5)
/SDA: J1.4, U1.23 (SDA)
/SDA_1: TOF1.4 (SDA), U1.4 (SD0)
/SDA_2: TOF2.4 (SDA), U1.6 (SD1)
/SDA_3: TOF3.4 (SDA), U1.8 (SD2)
/SDA_4: TOF4.4 (SDA), U1.10 (SD3)
/SDA_5: TOF5.4 (SDA), U1.13 (SD4)
/SDA_6: TOF6.4 (SDA), U1.15 (SD5)
GND: A0_0.1 (A), C1.2, J1.2, TOF1.2 (GND), TOF2.2 (GND), TOF3.2 (GND), TOF4.2 (GND), TOF5.2 (GND), TOF6.2 (GND), U1.2 (A1), U1.12 (GND), U1.21 (A2)
unnamed: A0_0.2 (B), A0_1.1 (A), U1.1 (A0)
unnamed: R1.2, U1.3 (~RESET)

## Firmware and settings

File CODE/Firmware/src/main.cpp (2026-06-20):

#include <Wire.h>

#include "defs.h"
#include "usb.h"
#include "air.h"
#include "slider.h"

static constexpr size_t REPORT_RATE = 1000;
static constexpr size_t REPORT_RATE_US = 1'000'000 / REPORT_RATE;

static chu_air air;
static chu_slider slider;
static chu_usb usb_hid { air, slider };

void setup() {
#if USE_SERIAL
    Serial.begin(115200);
    while (!Serial) { }
#endif

    Wire.setSDA(16);
    Wire.setSCL(17);
    Wire.begin();

    usb_hid.setup();

    // Emulate same device RedBoard expects
    // USBDevice.setID(0x0f0d, 0x0092);

    while (!USBDevice.mounted() && !usb_hid.ready()) {
        delay(1);
    }
}

void loop() {
    uint64_t next_tick = time_us_64() + REPORT_RATE_US;

    for (;;) {
        tud_task();

        usb_hid.tick();

        sleep_until(next_tick);
        next_tick += REPORT_RATE_US;
    }
}

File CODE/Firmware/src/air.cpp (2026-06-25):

#include "air.h"

#include <Wire.h>

#include "defs.h"

chu_air::chu_air() {

}

void chu_air::setup() {
#if USE_SERIAL
    Serial.printf("[chu_air] Initializing on %p, %zu boards with %zu sensors each\n", TOF_ADDR, TOF_BOARDS, TOF_COUNT);
#endif

    for (size_t i = 0; i < _sensors.size(); ++i) {
        VL53L0X& sensor = _select_sensor(i);

        sensor.setTimeout(500);

        if (sensor.init()) {
#if USE_SERIAL
            Serial.printf("[chu_air] Started sensor %zu (%i on %p)\n", i, i % TOF_COUNT, TOF_ADDR + (i / TOF_COUNT));
        } else {
            Serial.printf("[chu_air] Failed to start sensor %zu (%i on %p)\n", i, i % TOF_COUNT, TOF_ADDR + (i / TOF_COUNT));
            Serial.printf("          Last status: %i\n", (int)sensor.last_status);
#endif
        }

        sensor.startContinuous();
    }
}

uint8_t chu_air::tick() {
    uint8_t res = 0;

    size_t count_in_range = 0;
    for (size_t i = 0; i < _sensors.size(); ++i) {
        VL53L0X& sensor = _select_sensor(i);

        uint16_t dist = sensor.readRangeContinuousMillimeters();

        if (dist > AIR_OFFSET && dist < (AIR_OFFSET + (AIR_STEP * 6) + (AIR_STEP * 3))) {
            uint8_t height = (dist - AIR_OFFSET + AIR_STEP - 1) / AIR_STEP;
            
            res |= (1 << (height - 1));
        }
    }

    return res;
}

VL53L0X& chu_air::_select_sensor(uint8_t ch) {
    for (uint8_t addr = TOF_ADDR; addr < (TOF_ADDR + TOF_BOARDS); ++addr) {
        uint8_t data = 0;
        if (addr == TOF_ADDR + (ch / TOF_COUNT)) {
            data = 1 << (ch % TOF_COUNT);
        }

        Wire.beginTransmission(addr);
        Wire.write(data);
        Wire.endTransmission();
    }

    return _sensors[ch];
}

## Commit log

2026-06-17 more workinging Air boards, two of them now. Kinda broken but probably wiring or components.
    [air.cpp, main.cpp]
2026-06-22 PCB and CAD file update.
    [Chuni bottom case.3mf, chu-controller.step, chu-touch.step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]
2026-06-23 Removed button stay alive counting.
2026-06-25 updated air to be better
    [Center-Holder-Chu-Giga.3mf, Left-Holder-Chu-Giga.3mf, Right-Holder-Chu-Giga.3mf]
